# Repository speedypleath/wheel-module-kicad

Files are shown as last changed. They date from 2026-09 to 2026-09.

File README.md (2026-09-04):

# Haptic Console - Wheel Module (M3) Encoder Sensor Board

KiCad project for the electronics of the Wheel Module (M3) of Haptic Console v1.0,
part of the ITPMA dissertation *Tactile I/O: Exploring physicality in MIDI controllers*.

The mechanical side of this module (200 mm DIN aluminium handwheel, PETG shaft,
6204-2RS bearings, GT2 1:1 belt drive) is documented in the Obsidian vault under
`Notes/Haptic Console - Handwheel Belt Drive Module Plan.md`. This repository covers
only the sensor board that reads the optical encoder and presents it to the console.

## What the board does

The handwheel drives an E38S6G5-600B-G24N 600 P/R optical encoder through a 1:1 GT2
belt. A Raspberry Pi Pico reads the A/B quadrature signals locally, converts them into a clean position
packet, and exposes that packet to the Teensy 4.1 master over I2C. The module behaves
as a self-contained tactile sense organ rather than a peer processor, matching the
connector standard's design philosophy.

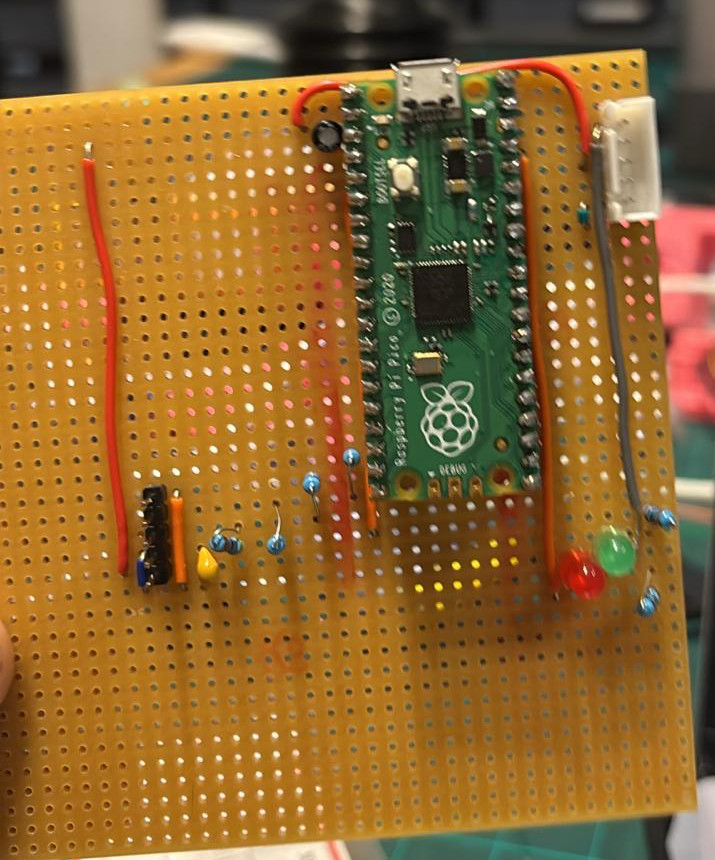
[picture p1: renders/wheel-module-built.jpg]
The Wheel Module encoder board, hand-wired on 2.54 mm protoboard


*The module as actually built. Component side, left to right: `J2` (black 5-pin encoder
header) and the pull-up/series resistors bottom left, `C2` (yellow disc) beside them,
`U1` centre with `C1`'s electrolytic can at its USB end, `J1` (white XH2.54 to the hub)
top right, and the `D1`/`D2` status LEDs bottom right.*

## The encoder interface, and why the pull-ups are there

The encoder is an **E38S6G5-600B-G24N**: photoelectric incremental, 600 P/R, rated
**DC 5-24V**, with **NPN open-collector** outputs. The `600B` suffix denotes **AB
two-phase — there is no Z index channel**. Absolute zero is established in firmware,
not from hardware index.

The open-collector output is the important electrical detail. An open-collector output can
only pull its line *low*. It never drives a line high. The high level is therefore set
entirely by whatever rail the line is pulled up to, and is completely independent of
the encoder's own supply voltage.

That gives the safety property this board relies on:

- `R1`, `R2` (4.7k) pull `ENC_A_RAW` and `ENC_B_RAW` up to **+3V3**.
- The Pico therefore sees a 0V to 3.3V swing regardless of whether the encoder is run
  from 5V or 12V.
- `R4`, `R5` (330R) sit in series into the Pico GPIO as fault-current limiters,
  protecting the pin if a line is ever accidentally shorted to the encoder supply.

4.7k is comfortable here. With ~2 m of encoder cable at roughly 120 pF/m plus pin and
stray capacitance (~300 pF total), the RC rise time is about 3 us 10-90%. At a realistic
handwheel speed of 300 rev/min each channel runs at 3 kHz, a 333 us period, so the rise
occupies under 1% of it. Pull-up current is 0.7 mA per line, far inside the output
stage's sink capability.

Without the pull-ups the inputs would float and the quadrature decode would be noise.
The pull-ups are not optional here.

Encoder power is taken from the console's **5V rail**, which is inside the encoder's
rated 5-24V window. If the encoder proves sluggish or noisy at 5V, the documented
alternative is a small 5V to 12V boost feeding `J2` pin 1 only. Because the pull-ups
reference 3.3V, that change requires **no** modification to the logic side.

**Decision, 2026-08-28: the 12V path is deliberately not built.** The planned Eurorack
translation module needs 24V regardless, so if a higher-voltage rail is ever added it
should be designed once for both modules rather than bolted onto M3 alone. Treat 5V as
the committed supply until that point. Note also that if the encoder signals ever look
sluggish, supply voltage is the *less* likely cause: edge shape here is set by the
pull-up RC (4.7k against ~300 pF, ~3 us) which does not change with encoder supply at
all. Rounded edges point at the pull-ups (fit 2.2k or 1k); missed counts that worsen
with rotation speed point at the supply.

## Console interface

`J1` is the standard **XH2.54 6-pin** inter-module connector (standard v1.1):

| Pin | Signal | Board use |
|---|---|---|
| 1 | GND | Common ground |
| 2 | 3.3V | **Not connected** (see below) |
| 3 | 5V | Powers the Pico via VSYS, and the encoder |
| 4 | SIG1 / SDA | I2C data, Pico GP4 |
| 5 | SIG2 / SCL | I2C clock, Pico GP5 |
| 6 | SIG3 / IRQ | Data-ready, Pico GP6 |

Pin 2 is deliberately left unconnected. The connector standard warns against feeding
both VSYS and 3V3 as competing power paths into a Pico. The board takes 5V into VSYS
and uses the Pico's own regulated 3V3 output as the logic reference for the pull-ups.

I2C bus pull-ups live on the master/hub board, not here, per the same standard.

## Encoder connector

`J2` is a 5-pin 2.54mm header matching the encoder's four conductors plus its shield:

| Pin | Encoder wire | Board use |
|---|---|---|
| 1 | Red | V+, from the console 5V rail |
| 2 | Black | 0V / GND |
| 3 | White | Channel A, to `R1`/`R4` |
| 4 | Green | Channel B, to `R2`/`R5` |
| 5 | Bare / foil | Cable shield, to GND |

Pin 5 carried `ENC_Z` in the first revision. The encoder has no Z channel, so it is now
the shield return, terminated to GND **at the board end only** — single-point, to avoid
a ground loop down the 2 m cable run.

## Pin map

| Pico pin | Net | Function |
|---|---|---|
| GP2 (pin 4) | LNK | Link/comms status LED |
| GP4 (pin 6) | SDA | I2C target data |
| GP5 (pin 7) | SCL | I2C target clock |
| GP6 (pin 9) | IRQ | Data-ready out to master |
| GP16 (pin 21) | ENC_A | Encoder channel A |
| GP17 (pin 22) | ENC_B | Encoder channel B |
| VSYS (pin 39) | +5V | Module power in |
| 3V3 (pin 36) | +3V3 | Logic reference out |

At 600 P/R with 4x quadrature decoding, one full handwheel turn is 2400 counts.

## Why C1 is there, and why it is an electrolytic

C1 is a **bulk reservoir**, not a decoupling capacitor, and the two jobs are
different. C2 (100 nF on 3V3) is decoupling: it kills the nanosecond-scale current
spikes from GPIO switching, and wants to be small and close to the pin. C1 sits on
the 5 V rail at the connector entry and does the opposite job — it is a local charge
store at the far end of the hub cable.

The 5 V arrives over a metre or two of XH2.54 flying lead, perhaps 1 uH/m of
inductance plus some milliohms. Every change in this board's load current has to be
supplied through that inductance: the encoder's output transistors switching at
2 x 3 kHz, the Pico's RT6150 buck-boost drawing pulsed input current, and above all
**hot-plugging J2 with the encoder attached**. Without local bulk the rail at VSYS
dips and rings instead of holding up. Steady-state draw is modest — encoder
40-100 mA, Pico 25-30 mA, LEDs ~3 mA — so it is the transients that matter.

100 nF will not do this job: it is 100x less charge. A 100 mA step lasting 300 ns
gives dV = I*dt/C ~= 300 mV on 100 nF against ~3 mV on 10 uF, and it moves the
cable-inductance resonance from ~50 kHz up to ~500 kHz where it is far less damped.

**Electrolytic is the right part, not a compromise** — bulk capacitance is what
aluminium electrolytics are for. The first revision specified a 10 uF ceramic only
because `Device:CP` cached as a zero-pin stub during project creation and switching
to the non-polarised `Device:C` sidestepped the question. (The real cause was
simpler: KiCad 10 has no `Device:CP` at all; the symbol is `Device:C_Polarized`.)

**C1 is now polarised, and nothing in ERC or DRC will catch it if you fit it
backwards.** Pad 1 is **+** and goes to `+5V`; the lead beside the printed stripe is
**-** and goes to `GND`. On a 5 V rail a reversed electrolytic will vent. Both build
guides call this out at the step where it matters.

## Bill of materials

| Ref | Value | Footprint |
|---|---|---|
| U1 | Raspberry Pi Pico | Module:RaspberryPi_Pico_Common_THT |
| J1 | XH2.54 6-pin console connector | Connector_JST:JST_XH_B6B-XH-A_1x06_P2.50mm_Vertical |
| J2 | 5-pin encoder header | Connector_PinHeader_2.54mm:PinHeader_1x05_P2.54mm_Vertical |
| R1, R2 | 4.7k pull-up to 3.3V | Resistor_THT:R_Axial_DIN0207_L6.3mm_D2.5mm_P10.16mm_Horizontal |
| R4, R5 | 330R series protection | Resistor_THT:R_Axial_DIN0207_L6.3mm_D2.5mm_P10.16mm_Horizontal |
| R7, R8 | 1k LED current limit | Resistor_THT:R_Axial_DIN0207_L6.3mm_D2.5mm_P10.16mm_Horizontal |
| C1 | 10uF 25V bulk on 5V, **polarised** | wheel-module:CP_Radial_D4.0mm_P2.50mm |
| C2 | 100nF decoupling on 3.3V | Capacitor_THT:C_Disc_D5.0mm_W2.5mm_P5.00mm |
| D1 | PWR green 3mm | LED_THT:LED_D3.0mm |
| D2 | LNK red 3mm | LED_THT:LED_D3.0mm |

D1 and D2 match the PWR/LNK status cluster in the front panel drawing
(`Notes/Haptic Console - Wheel Module Front Panel.md`).

## Layouts and build guides

One schematic, three board files. They share the netlist and nothing else — pick the one
that matches how you are building.

| Build | Board file | Build guide |
|---|---|---|
| Stripboard (Veroboard) | `project/haptic-console-wheel-module-stripboard.kicad_pcb` | [`docs/stripboard-wiring.md`](docs/stripboard-wiring.md), or the interactive [`docs/stripboard-wiring.html`](docs/stripboard-wiring.html) with a live board map |
| Plain perfboard | `project/haptic-console-wheel-module-perfboard.kicad_pcb` | [`docs/perfboard-wiring.md`](docs/perfboard-wiring.md) |
| Fabricated PCB | `project/haptic-console-wheel-module.kicad_pcb` | none needed — [Gerber set](project/haptic-console-wheel-module-gerbers.zip) |

### Schematic

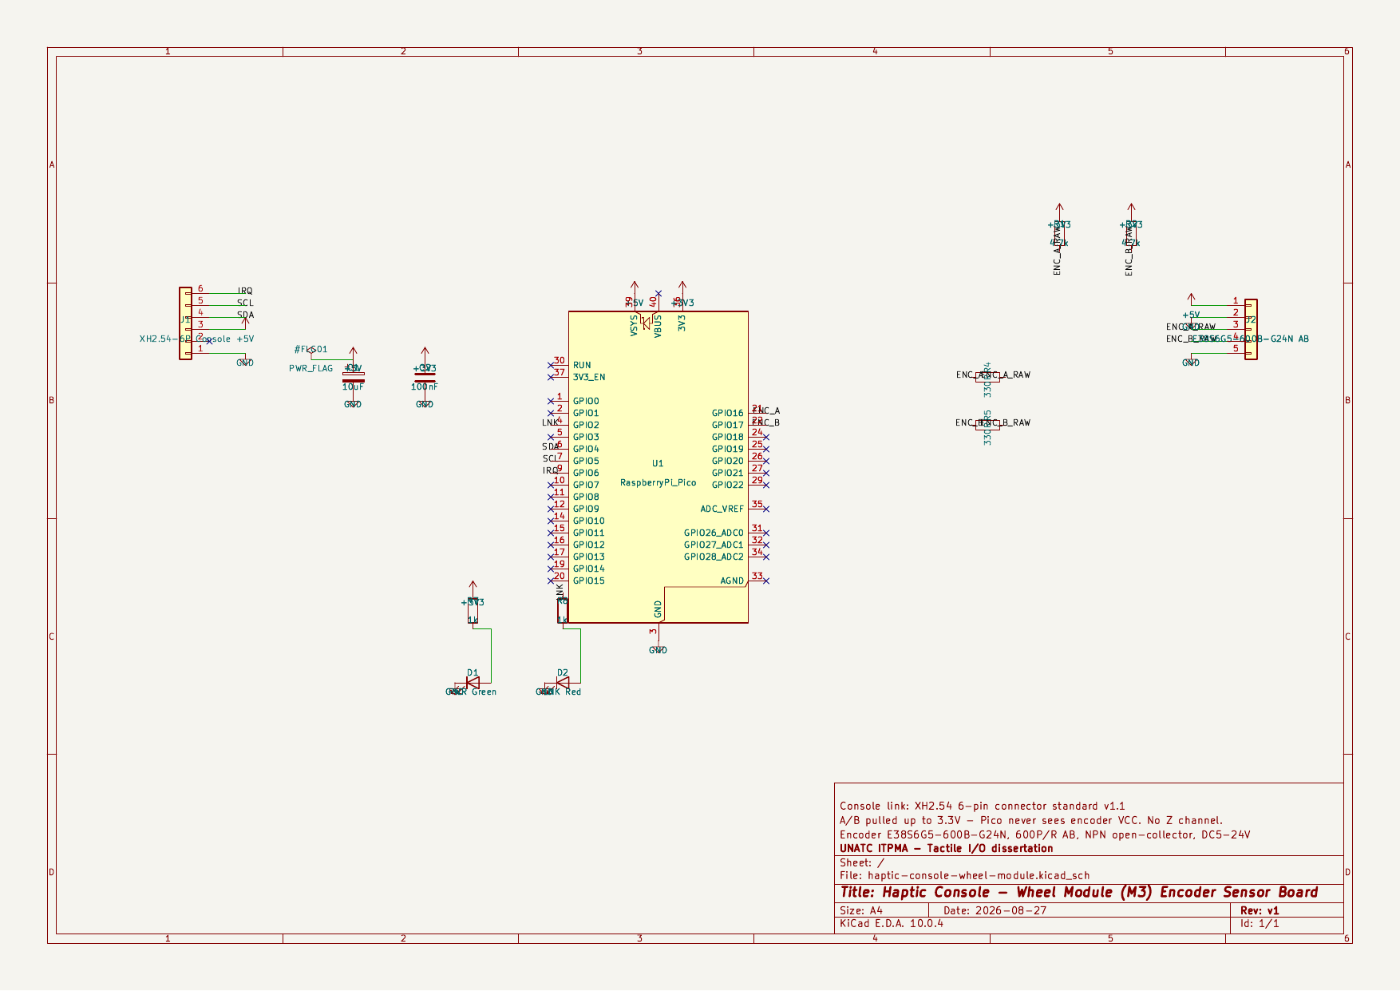
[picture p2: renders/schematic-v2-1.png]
Schematic


Full page as [`renders/schematic-v2.pdf`](renders/schematic-v2.pdf). ERC report:
[`docs/erc-report.txt`](docs/erc-report.txt); exported netlist:
[`docs/netlist.net`](docs/netlist.net).

### Stripboard (Veroboard)

40 x 40 holes, 104.14 mm square — the full uncut board. The circuit lives in cols 1-28 /
rows 1-28; the strips run the board's whole width regardless, which is why the audit
matters more than the placement.

| Component side | Solder side |
|---|---|
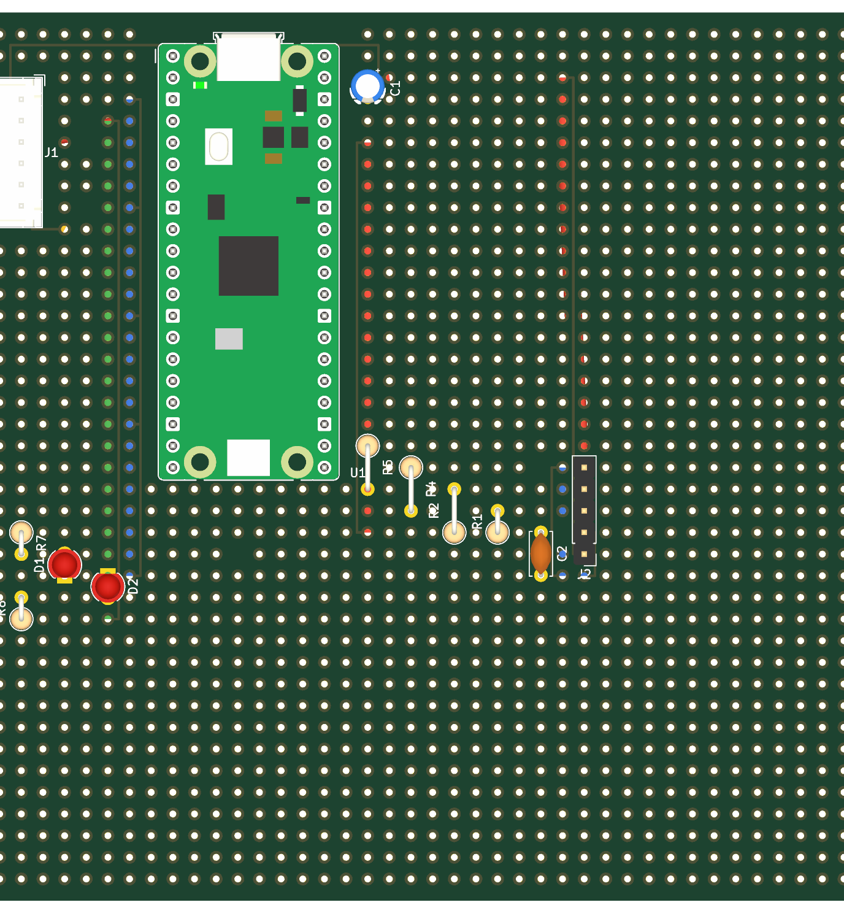
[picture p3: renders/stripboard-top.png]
Stripboard, component side
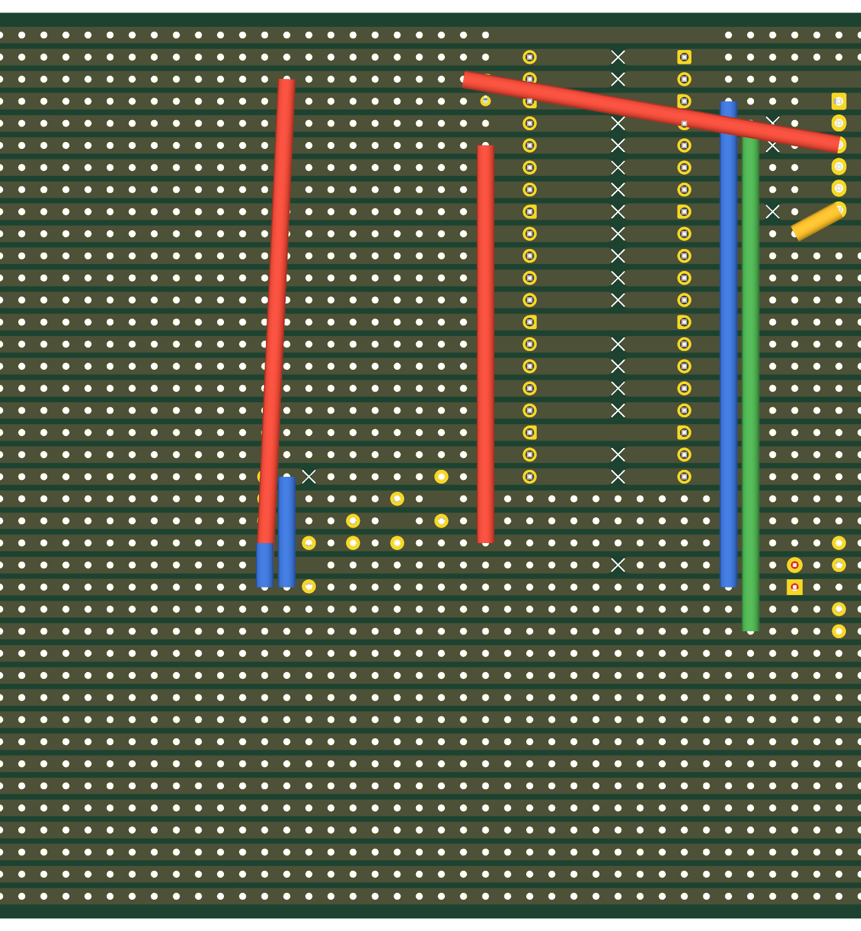
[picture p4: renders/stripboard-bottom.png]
Stripboard, solder side
|  |  |

The solder-side view is the one to build from: white `X` marks are the 23 track cuts, and
the coloured rods are the eight link wires, drawn to the control unit's colour convention
(red power, blue GND, yellow I2C/IRQ, green `/LNK`). Cuts and links are listed
step-by-step in [`docs/stripboard-wiring.md`](docs/stripboard-wiring.md).

### Plain perfboard

28 x 28 holes, 71.12 mm square, every connection a discrete wire.

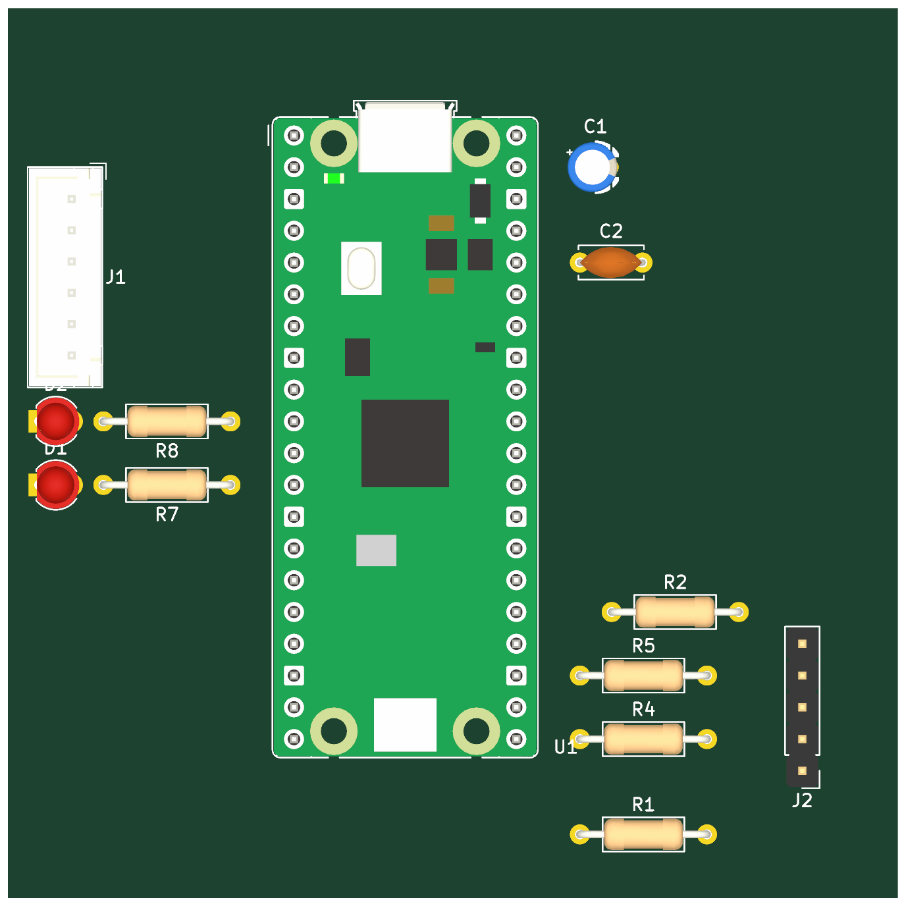
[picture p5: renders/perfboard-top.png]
Perfboard, component side


Wire-by-wire build order in [`docs/perfboard-wiring.md`](docs/perfboard-wiring.md).

### Fabricated PCB

68 x 58 mm, 2-layer, all through-hole.

| Front (F.Cu) | Back (B.Cu) |
|---|---|
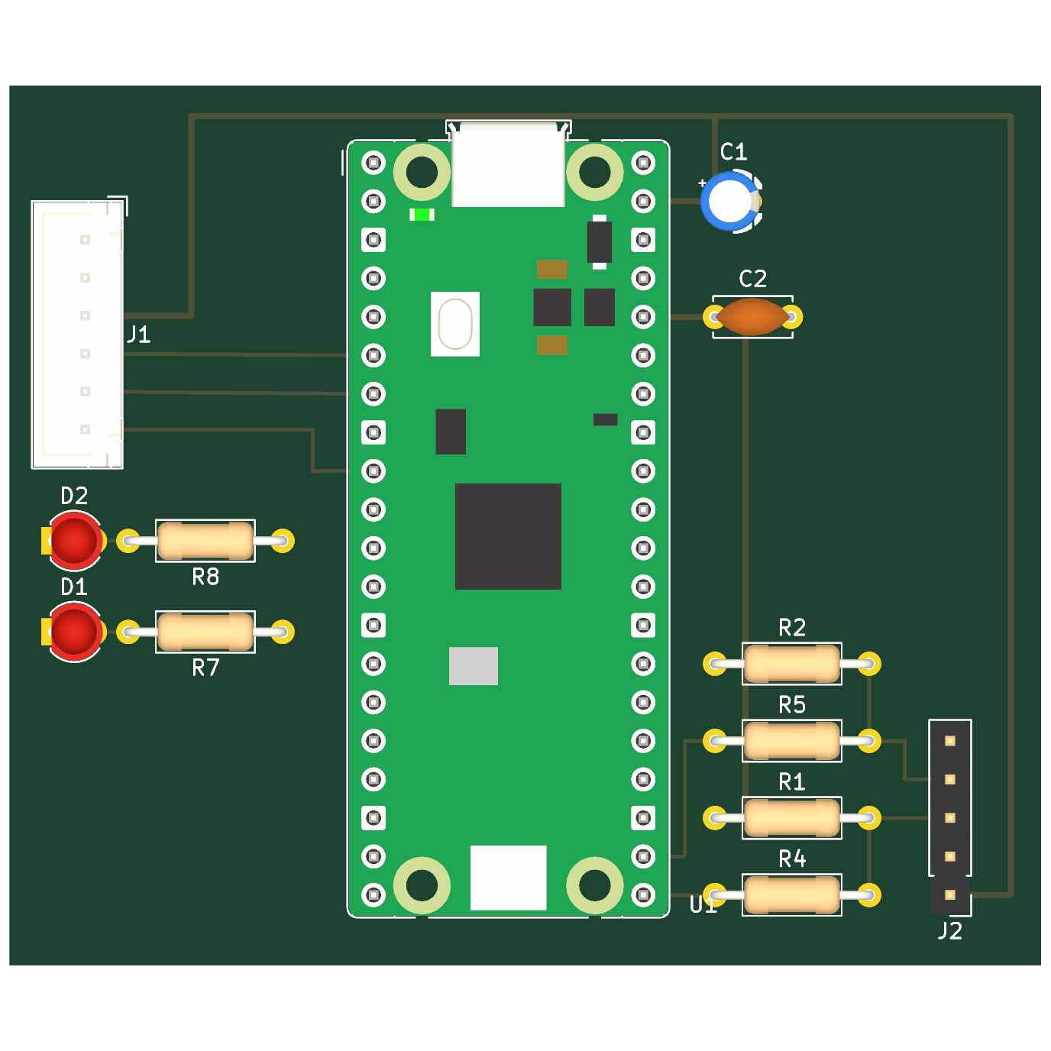
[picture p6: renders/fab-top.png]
Fabricated PCB, front
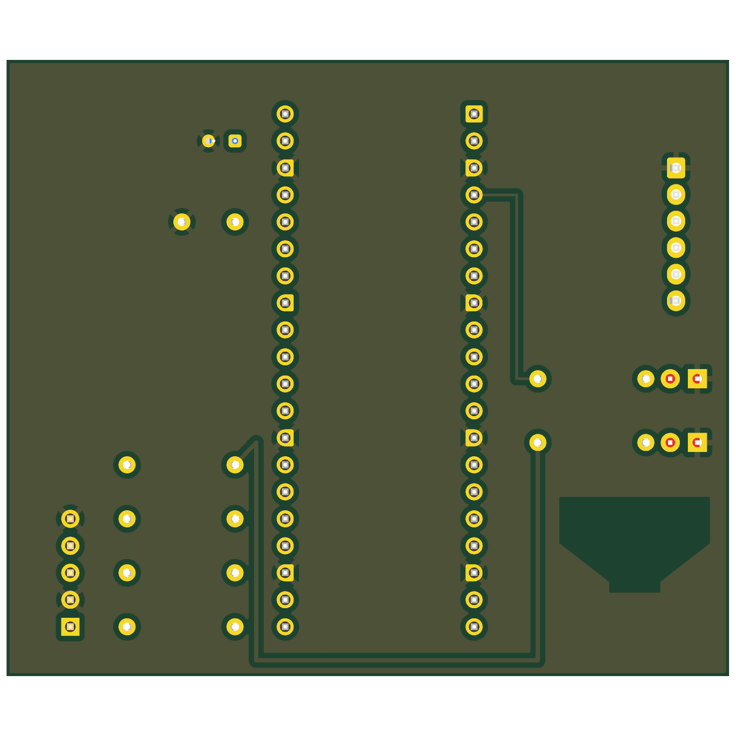
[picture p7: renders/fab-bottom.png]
Fabricated PCB, back
|  |  |

The back is mostly the filled GND pour that all 14 GND pads tie into; only `/LNK` and the
`+3V3` branch to `R7` are routed there.

## Status

- Schematic: complete, **ERC 0 errors / 0 warnings**, netlist verified by parsing the
  exported `docs/netlist.net` — 13 components, 15 nets, every node checked against the
  pin map above. A clean ERC alone does not prove connectivity; always read the netlist.
- Encoder revision: `ENC_Z`, `R3` and `R6` removed after the datasheet confirmed the
  `600B` part is AB two-phase. `J2` pin 5 repurposed as shield. GP18 is now free.
- Perfboard layout: **complete**, 28x28 holes on 2.54mm pitch (71.12 x 71.12 mm cut),
  **0 DRC errors / 9 cosmetic warnings**. Every pad verified on-grid with no shared
  holes. The 32 unconnected pads DRC reports are expected -
  the board is hand-wired and carries no copper traces.
- Stripboard (Veroboard) layout: **complete**, 40x40 holes on 2.54mm pitch
  (104.14 mm square, the full uncut board), **0 DRC errors / 0 unconnected pads**.
  The circuit occupies cols 1-28 / rows 1-28; the rest is spare board, but the
  strips still run its full width. Continuous copper
  strips, 23 track cuts, 11 link connections. Two cuts are
  load-bearing: row 9 keeps **AGND** off the GND bus, and column 5 keeps `J1` pin 2
  (hub 3.3V) unconnected. Rows 4/14/19 are left uncut on purpose - they carry GND on
  both sides of the Pico and form the GND bus for free. The ~240 DRC warnings are
  expected: perfboard holes modelled as vias dangle by construction.
  Generated from `scripts/layout.py` by the shared `~/KiCad/kicad-stripboard`
  engine - rebuild it rather than editing the board.
  The eight physical link wires are modelled as colour-coded 3D jumper wires on the
  **solder** side, keeping the crowded component side clear.
- Manufactured PCB layout: **complete**, 2-layer, 68 x 58 mm, all through-hole.
  **0 DRC errors, 0 shorts, 0 unconnected items** — every net is connected. 38 routed
  segments plus a filled GND pour on `B.Cu` (3270 mm² of copper), which all 14 GND pads
  tie into directly, so GND needs no traces. Two runs sit on the back layer because they would otherwise cross the J1 signal fan
  on the front: `/LNK` (U1.4 → R8.1) and the `+3V3` branch feeding R7, which goes round
  the bottom at y=56.5 rather than threading the 0.94 mm gaps between the Pico's pad
  rows. The front `+3V3` spine is offset to x=48.5 rather than running down the x=46.5
  pad column, because R5.1 (`/ENC_B`) sits mid-column at 46.5,43.18.
- Cosmetic: reference and value text is auto-placed and overlaps net labels in a few
  places. Harmless electrically, but worth a tidy-up pass in the GUI before the
  schematic goes into the dissertation.

## Verification

```bash
export KICAD_SYMBOL_DIR=/Applications/KiCad/KiCad.app/Contents/SharedSupport/symbols
export KICAD_FOOTPRINT_DIR=/Applications/KiCad/KiCad.app/Contents/SharedSupport/footprints
kicad-cli sch erc --format report project/haptic-console-wheel-module.kicad_sch -o docs/erc-report.txt
kicad-cli sch export netlist --format kicadsexpr project/haptic-console-wheel-module.kicad_sch -o docs/netlist.net
```

Setting both environment variables matters. Without them `kicad-cli` cannot resolve the
stock libraries and reports spurious violations.

## Related

- [`docs/perfboard-wiring.md`](docs/perfboard-wiring.md) - hand-wiring guide for the
  plain-perfboard build
- [`docs/stripboard-wiring.md`](docs/stripboard-wiring.md) - cut/link build guide for the
  Veroboard build, plus the interactive
  [`docs/stripboard-wiring.html`](docs/stripboard-wiring.html)
- [`scripts/layout.py`](scripts/layout.py) - the stripboard layout as data; source of
  truth for that board
- `../kicad-stripboard` - the shared engine that builds and audits strip board layouts
- `../control-unit-kicad` - the Control Unit (M6) board, already fab-ready
- Obsidian: `Notes/Haptic Console - Connector Standard.md`
- Obsidian: `concepts/haptic-console-wheel-module.md`

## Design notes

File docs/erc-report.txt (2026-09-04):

ERC report (2026-09-03T21:16:04, Encoding UTF8)
Report includes: Errors, Warnings

***** Sheet /

 ** ERC messages: 0  Errors 0  Warnings 0

 ** Ignored checks:
    - Global label only appears once in the schematic
    - Four connection points are joined together
    - Assigned footprint doesn't match footprint filters

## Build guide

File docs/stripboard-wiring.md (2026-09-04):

# Stripboard wiring guide — Wheel Module (M3) encoder sensor board

Build reference for `project/haptic-console-wheel-module-stripboard.kicad_pcb`.
Generated from the placed board; grid resized to the real 40 x 40 stock on
2026-08-30. Circuit itself is in `README.md`.

There is an interactive version of this document at
[`docs/stripboard-wiring.html`](stripboard-wiring.html) — same content, plus a
board map, a searchable cut list and a tickable solder checklist. Open it in a
browser; it is a single self-contained file.

This is the **Veroboard** build. It is a different board from
`docs/perfboard-wiring.md`, which covers the point-to-point plain-perfboard build.
Pick one; they are not interchangeable.

## Grid convention

Continuous-strip Veroboard, **40 columns × 40 rows** on 2.54 mm — a full
**104.14 mm square** board, uncut. Copper strips run **horizontally**, one per
row, the full width of the board.

```
x = col * 2.54 mm        col 1..40, left to right
y = row * 2.54 mm        row 1..40, top to bottom
```

The circuit occupies **cols 1–28, rows 1–28**, in the top-left corner. Everything
right of column 28 and below row 28 is spare board. That spare copper is not
inert: each strip still runs the full 40 columns, so the right-hand end of a row
is electrically the same node as the part of it the circuit uses. Treat it as
free tie points, and keep it clear of stray solder bridges between rows.

`(1,1)` is the top-left hole, with one clear 2.54 mm margin on every edge. All
column/row references below are given **component side, Pico USB at the top** —
matching `renders/stripboard-top.png`. Remember the copper is on the **back**, so
when you flip the board to cut, columns mirror.

**Row 1 carries nothing.** The Pico's body is 51 mm long but spans only 19 pin
pitches (48.26 mm), so it overhangs its end rows by 1.37 mm: the body edge sits
at y = 3.71 mm while a row-1 hole's copper ends at 3.29 mm. That is 0.42 mm of
daylight — real, but not worth soldering into. The USB shell overhangs a further
1.3 mm on top of that, though it rides 8.5 mm up in the air on the socket
headers and fouls nothing.

## Read this first: the strip is shared by every hole in its row

On plain perfboard a hole connects to nothing. Here it connects to the whole row.
So a pin you never wired still shorts to whatever else sits on its strip. Two
consequences drove this entire layout:

- **Row 9 must be cut at column 12.** Pico pin 8 (GND) is on the left of that
  row and pin 33 (**AGND**) is on the right. AGND is a deliberate no-connect —
  tying it to GND re-creates the `power_out`/`power_out` ERC violation documented
  in `CLAUDE.md`. Leave that cut out and you have broken a design invariant.
- **Rows 4, 14 and 19 are deliberately NOT cut.** Those three rows carry GND on
  *both* sides of the Pico (pins 3/38, 13/28, 18/23), so leaving them whole gives
  six GND connections for free and forms the GND bus.

### And why `+5V` has no strip of its own

A strip that spans the Pico is only safe on a row whose two pins are the same
net, and the only such rows are the three GND ones. So `+5V` cannot have a
full-width rail. It lives on **row 3's right-hand segment**, where the Pico's
own VSYS pin and `C1` already sit, and the hub's 5 V — which arrives on the far
left at `J1.3` — is carried over the top of the module to reach it (wire 1).
Row 3's *left* segment must stay cut off at column 12: it carries Pico pin 2,
GPIO1, and 5 V on a GPIO would destroy the chip.

## Cuts — 23 of them

Cut with a spot-face cutter or a 3 mm drill twisted by hand, **at the hole**,
from the copper side. Each cut removes the copper around one hole; that hole is
then dead. Marked with an `X` on the back silkscreen in the render.

| Column | Rows | Why |
|---|---|---|
| **12** | 2, 3, 5, 6, 7, 8, 9, 10, 11, 12, 13, 15, 16, 17, 18, 20, 21 | Splits the Pico's left pins from its right pins. **Not** 4/14/19 — those stay whole as the GND bus. |
| **12** | 25 | Separates `Net-(D1-A)` (left) from `+5V` (right). |
| **5** | 5, 6, 9 | Isolates `J1` pins 2, 3 and 6, whose order disagrees with the Pico's. |
| **26** | 21 | Isolates `J2.5` (shield GND) from `/ENC_A`. |
| **27** | 24 | Isolates `J2.2` (GND) from `+3V3`. |

Count them before soldering anything. A missed cut on row 9 or row 3 is the
expensive kind.

## Strip allocation

Every strip segment carries exactly one net — verified against the saved board,
not against intent.

| Row | Columns | Net | Pads on it |
|---|---|---|---|
| 1 | all | *(spare — under the module overhang)* | — |
| 2 | 1–11 / 13–40 | *(unused Pico pins)* | U1.1 / U1.40 |
| 3 | 1–11 | *(unused)* | U1.2 |
| 3 | 13–40 | `+5V` | U1.39, C1.1 |
| **4** | **all (uncut)** | `GND` | U1.3, U1.38, J1.1, C1.2 |
| 5 | 1–4 | *(no-connect)* | **J1.2 — hub 3.3V, must stay isolated** |
| 5 | 6–11 | `/LNK` | U1.4 |
| 5 | 13–40 | *(unused)* | U1.37 |
| 6 | 1–4 | `+5V` | J1.3 |
| 6 | 6–11 | *(unused)* | U1.5 |
| 6 | 13–40 | `+3V3` | U1.36 |
| 7 | 1–11 | `/SDA` | U1.6, J1.4 |
| 7 | 13–40 | *(unused)* | U1.35 |
| 8 | 1–11 | `/SCL` | U1.7, J1.5 |
| 8 | 13–40 | *(unused)* | U1.34 |
| 9 | 1–4 | `/IRQ` | J1.6 |
| 9 | 6–11 | `GND` | U1.8 |
| 9 | 13–40 | *(no-connect)* | **U1.33 AGND — must stay isolated** |
| 10 | 1–11 | `/IRQ` | U1.9 |
| 10 | 13–40 | *(unused)* | U1.32 |
| 11–13, 15–18 | 1–11 / 13–40 | *(unused Pico pins)* | one per side, bare |
| **14** | **all (uncut)** | `GND` | U1.13, U1.28 |
| **19** | **all (uncut)** | `GND` | U1.18, U1.23 |
| 20 | 1–11 | *(unused)* | U1.19 |
| 20 | 13–40 | `/ENC_B` | U1.22, R5.1 |
| 21 | 1–11 | *(unused)* | U1.20 |
| 21 | 13–25 | `/ENC_A` | U1.21, R4.1 |
| 21 | 27–40 | `GND` | J2.5 |
| 22 | all | `/ENC_B_RAW` | R5.2, R2.2, J2.4 |
| 23 | all | `/ENC_A_RAW` | R4.2, R1.2, J2.3 |
| 24 | 1–26 | `+3V3` | R7.1, R2.1, R1.1, C2.1 |
| 24 | 28–40 | `GND` | J2.2 |
| 25 | 1–11 | `Net-(D1-A)` | R7.2, D1.2 |
| 25 | 13–40 | `+5V` | J2.1 |
| 26 | all | `GND` | D1.1, D2.1, C2.2 |
| 27 | all | `Net-(D2-A)` | D2.2, R8.2 |
| 28 | all | `/LNK` | R8.1 |
| 29–40 | all | *(spare board)* | — |

63 strip segments in total, across 1331 holes.

## Placement

Pad 1 sits at the stated hole for every part. **All six resistors stand on end**
— this is the Veroboard idiom and it is what stops them shorting along a strip.

| Ref | Value | Footprint | Pad 1 | Occupies |
|---|---|---|---|---|
| U1 | Pico | `RaspberryPi_Pico_Common_THT` | (9,2) | cols 9 & 16, rows 2–21 |
| J1 | XH2.54 6-pin | `JST_XH_B6B-XH-A_1x06_P2.50mm_Vertical` | (2,4) | col 2, rows 4–9 |
| J2 | 5-pin header | `PinHeader_1x05_P2.54mm_Vertical` | (28,25) | col 28, rows 21–25, **pin 1 at the bottom** |
| R1 | 4.7k | `R_Axial_..._P2.54mm_Vertical` | (24,24) | col 24, rows 23–24 |
| R2 | 4.7k | `R_Axial_..._P5.08mm_Vertical` | (22,24) | col 22, rows 22–24 |
| R4 | 330R | `R_Axial_..._P5.08mm_Vertical` | (20,21) | col 20, rows 21–23 |
| R5 | 330R | `R_Axial_..._P5.08mm_Vertical` | (18,20) | col 18, rows 20–22 |
| R7 | 1k | `R_Axial_..._P2.54mm_Vertical` | (2,24) | col 2, rows 24–25 |
| R8 | 1k | `R_Axial_..._P2.54mm_Vertical` | (2,28) | col 2, rows 27–28 |
| C1 | 10uF 25V | `wheel-module:CP_Radial_D4.0mm_P2.50mm` | (18,3) | col 18, rows 3–4, **pad 1 = + = row 3** |
| C2 | 100nF | `C_Disc_D5.0mm_W2.5mm_P5.00mm` | (26,24) | col 26, rows 24–26 |
| D1 | power LED | `LED_D3.0mm` | (4,26) | col 4, rows 25–26, pad 1 = cathode = GND |
| D2 | link LED | `LED_D3.0mm` | (6,26) | col 6, rows 26–27, pad 1 = cathode = GND |

**C1 is polarised.** It is a D4x7 aluminium electrolytic, not the ceramic disc the
first revision carried. Pad 1 is the **+** lead and belongs on row 3 (the `+5V` strip);
the lead beside the printed stripe is **−** and goes to row 4 (`GND`). Fitted the wrong
way round it can vent. Its footprint is drawn project-local, in
`libraries/wheel-module.pretty`: no stock `CP_Radial` pairs a 4 mm can with the
2.50 mm pitch the 2.54 mm grid needs, and the stock 5 mm can is 1 mm too wide —
wide enough that its courtyard overlapped the Pico here and pushed C1 three holes
right for no physical reason.

Two parts are very slightly off-grid and this is fine — the leads bend:

- `J1` is a 2.50 mm connector on a 2.54 mm grid: pin 6 lands 0.2 mm above row 9,
  cumulative over six pins. XH pins are 0.6 mm in 1.0 mm holes.
- `C1` (2.50 mm) and `C2` (5.00 mm) are 0.04 mm and 0.08 mm out respectively.

`R4` and `R5` are the nicest part of this layout: they reach straight from the
Pico's `/ENC_A`/`/ENC_B` pins down to the `_RAW` rows with **no link wire at
all**, so the two noise-sensitive nets are pure copper.

## Link wires — 8 of them

**Insulated wire on the solder side**, hole to hole. The component side is
crowded — the Pico spans twenty rows and `J1`, `J2` and the LEDs sit on the very
edges the long links follow — so wires there would lie across component bodies.
The back is flat: insulated wire over a copper strip touches nothing.

Colours follow the console convention, shared with the control unit so the same
net is the same colour on every board: **red** for power (`+5V` and `+3V3` both —
the kit has six colours and consistency across boards wins over telling the two
rails apart at a glance), **blue** for GND (the kit has no black), **yellow** for
the I²C/IRQ bus, **green** for `/LNK`.

| # | Net | Colour | From | To | Purpose |
|---|---|---|---|---|---|
| 1 | `+5V` | red | (2,6) `J1.3` | (19,3) | console 5V over the module to the `+5V` rail |
| 2 | `/IRQ` | yellow | (2,9) `J1.6` | (4,10) | J1's IRQ pin down to the Pico's |
| 3 | `+5V` | red | (27,3) | (28,25) `J2.1` | rail down to the encoder connector |
| 4 | `+3V3` | red | (18,6) | (18,24) | Pico 3V3 out to the pull-up rail |
| 5 | `/LNK` | green | (6,5) | (6,28) | Pico GP2 down to the LED resistor |
| 6 | `GND` | blue | (7,4) | (7,26) | GND spine — **solder it also at rows 9, 14 and 19 on the way past** |
| 7 | `GND` | blue | (27,21) | (27,26) | `J2.5` cable shield to GND |
| 8 | `GND` | blue | (28,24) | (28,26) | `J2.2` encoder GND to GND |

Wire 6 is one length soldered at five holes — rows 4, 9, 14, 19 and 26. Those
three intermediate joints are what tie the Pico's GND rows into one bus; skipping
any of them leaves that row floating. (The board file models them as three extra
zero-length links, which is why the netlist counts eleven and this table eight.)

Wire 1 is the long one. It runs from `J1.3` up the outside of column 2, across
above the module in the gutter between rows 1 and 2, and down to (19,3). Its
copper track passes 1.27 mm from the row-2 Pico pins — 0.32 mm of clearance — so
keep the physical wire pulled up against the module's top edge rather than
letting it wander down over the pins. It crosses wires 5 and 6 on the way; all
three are insulated, so let 1 lie over them.

Wire 8 passes directly over `J2` pin 1, where wire 3 lands. Both are insulated —
let 8 lie over 3 rather than trying to dodge it.

## Optical Encoder (J2) & Console (J1) External Wiring

### Optical Encoder Wiring (`J2` — 5-Pin Header)

Target Encoder: **E38S6G5-600B-G24N** (NPN open-collector, 600 P/R).

| `J2` Pin | Stripboard Position (Col, Row) | Board Net | Encoder Wire Color | Function / Signal Path |
|---|---|---|---|---|
| **Pin 1** | **(28, 25)** *(Bottom)* | `+5V` | **Red** | Encoder DC Power Supply (+5V) |
| **Pin 2** | **(28, 24)** | `GND` | **Black** | Encoder Power Ground (0V) |
| **Pin 3** | **(28, 23)** | `/ENC_A_RAW` | **White** | Phase A &rarr; pull-up `R1` (4.7k) &rarr; `R4` (330R) &rarr; Pico `GP16` |
| **Pin 4** | **(28, 22)** | `/ENC_B_RAW` | **Green** | Phase B &rarr; pull-up `R2` (4.7k) &rarr; `R5` (330R) &rarr; Pico `GP17` |
| **Pin 5** | **(28, 21)** *(Top)* | `GND` (Shield) | **Bare / Braid** | Cable shield drain (single-point to board GND) |

#### Physical Header Orientation (Component Side, Pico USB UP):
```text
               [ Pico USB Top ]
  
  (Col 28, Row 21)  [ Pin 5 ]  <--- BARE BRAID (Cable Shield)
  (Col 28, Row 22)  [ Pin 4 ]  <--- GREEN      (Phase B)
  (Col 28, Row 23)  [ Pin 3 ]  <--- WHITE      (Phase A)
  (Col 28, Row 24)  [ Pin 2 ]  <--- BLACK      (Ground 0V)
  (Col 28, Row 25)  [ Pin 1 ]  <--- RED        (+5V Power)
  
              [ Bottom Edge ]
```

- **Shield Ground:** Terminate shield braid to Pin 5 *at this board end only* to prevent ground loops along the 2 m cable.
- **Open-Collector Logic:** Encoder outputs pull to GND; board pull-ups (`R1`, `R2`) pull up to +3.3V, ensuring Pico GPIO safety.
- **Pre-Flight DMM Checks:** Power board, measure Pin 1 &rarr; Pin 2 (+5.0V) and Pins 3/4 &rarr; GND (+3.3V) before plugging encoder in.

### Console Harness Wiring (`J1` — XH2.54 6-Pin Connector)

| `J1` Pin | Position (Col, Row) | Net | Function |
|---|---|---|---|
| **Pin 1** | **(2, 4)** *(Top)* | `GND` | Common system ground (Row 4 GND bus) |
| **Pin 2** | **(2, 5)** | `NC (Isolated)` | Console 3.3V &mdash; **must stay isolated** |
| **Pin 3** | **(2, 6)** | `+5V` | Console 5V DC power in &rarr; Pico VSYS |
| **Pin 4** | **(2, 7)** | `/SDA` | I²C Data &rarr; Pico `GP4` |
| **Pin 5** | **(2, 8)** | `/SCL` | I²C Clock &rarr; Pico `GP5` |
| **Pin 6** | **(2, 9)** *(Bottom)* | `/IRQ` | Interrupt line &rarr; Pico `GP6` |

## Build order

1. **Make all 23 cuts first**, before any part goes in. Check each one for
   continuity across the gap — a partial cut is the hardest fault to find later.
2. **Fit the Pico on female headers**, not soldered down. Two GND strips and the
   whole cut column run underneath it.
3. **Resistors, LEDs, caps.** All resistors vertical. Watch LED polarity: pad 1
   is the cathode and goes to the GND row (26) for both.
4. **`J1` and `J2`.**
5. **Link wires last.** They go on the *solder* side, so they follow the parts
   rather than preceding them: each end lands in the named hole and is soldered
   to that strip alongside the component lead already there. Strip and tin both
   ends first — a wire soldered onto an already-crowded joint is the easiest one
   to lift by accident.
6. Before power-up, check with a meter: `+5V` to `GND` open, `+3V3` to `GND`
   open, and **`U1.33` (AGND) isolated from GND** — that last one is the specific
   thing this layout's row-9 cut exists to guarantee.

## Verification state

- `kicad-cli pcb drc`: **0 errors, 0 unconnected pads, 0 footprint errors.**
- Strip audit (`every segment carries exactly one net`): **clean**, including the
  two isolation invariants above.
- 240 DRC *warnings* remain, all `via_dangling`/`track_dangling` plus three
  pre-existing `lib_footprint_mismatch`. These are expected — see `CLAUDE.md`.

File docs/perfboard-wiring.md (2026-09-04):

# Perfboard wiring guide — Wheel Module (M3) encoder sensor board

Hand-wiring reference for `project/haptic-console-wheel-module-perfboard.kicad_pcb`.
Generated from the placed board on 2026-08-28. Circuit itself is in `README.md`.

## Grid convention

Plain 2.54 mm perfboard, cut to **71.12 × 71.12 mm** (28 × 28 holes).

A hole is addressed as **(col, row)**, both 1-based from the top-left corner:

```
x = col * 2.54 mm        col 1..28, left to right
y = row * 2.54 mm        row 1..28, top to bottom
```

So (1,1) is the top-left hole and there is one clear 2.54 mm margin on every edge.
This matches the orientation of `renders/perfboard-top.png` — view from the
**component side**, Pico USB connector at the top.

## Placement summary

| Ref | Occupies | Notes |
|---|---|---|
| U1 Pico | cols 9 and 16, rows 4–23 | pin 1 at (9,4); left pin row descends, right pin row ascends |
| J1 console XH6 | col 2, rows 6–11 | pin 1 (GND) at top |
| J2 encoder 1x05 | col 25, rows 20–24 | **pin 1 at the bottom** (row 24), footprint is rotated 180° |
| R1, R2 | rows 26 and 19 | 4.7k pull-ups to +3V3 |
| R4, R5 | rows 23 and 21 | 330R series protection |
| R7, R8 | rows 15 and 13, cols 3–7 | 1k LED limiters, rotated 180° |
| D1, D2 | cols 1–2, rows 15 and 13 | pad 1 = cathode = GND |
| C1, C2 | C1 cols 18–19 row 5, C2 cols 18–20 row 8 | bulk (polarised) and decoupling |

Resistors sit two rows apart so the axial bodies never touch.

**C1 is polarised** — a 10 µF 25 V D4x7 electrolytic. Pad 1 is **+** and goes to (18,5)
on `+5V`; the striped **−** lead goes to (19,5) on `GND`. It spans two holes rather
than three because the electrolytic's leads are 2.5 mm apart, not 5 mm.

## Nets

| Net | Pads (col,row) |
|---|---|
| `+3V3` | **U1.36** (16,8) — **C2.1** (18,8) — **R7.1** (7,15) — **R2.1** (19,19) — **R1.1** (18,26) |
| `+5V` | **U1.39** (16,5) — **C1.1** (18,5) — **J1.3** (2,8) — **J2.1** (25,24) |
| `/ENC_A` | **U1.21** (16,23) — **R4.1** (18,23) |
| `/ENC_A_RAW` | **J2.3** (25,22) — **R4.2** (22,23) — **R1.2** (22,26) |
| `/ENC_B` | **R5.1** (18,21) — **U1.22** (16,22) |
| `/ENC_B_RAW` | **R2.2** (23,19) — **R5.2** (22,21) — **J2.4** (25,21) |
| `/IRQ` | **J1.6** (2,11) — **U1.9** (9,12) |
| `/LNK` | **U1.4** (9,7) — **R8.1** (7,13) |
| `/SCL` | **J1.5** (2,10) — **U1.7** (9,10) |
| `/SDA` | **J1.4** (2,9) — **U1.6** (9,9) |
| `GND` | **C1.2** (19,5) — **J1.1** (2,6) — **U1.3** (9,6) — **U1.38** (16,6) — **C2.2** (20,8) — **U1.8** (9,11) — **D2.1** (1,13) — **D1.1** (1,15) — **U1.13** (9,16) — **U1.28** (16,16) — **J2.5** (25,20) — **U1.18** (9,21) — **U1.23** (16,21) — **J2.2** (25,23) |
| `Net-(D1-A)` | **D1.2** (2,15) — **R7.2** (3,15) |
| `Net-(D2-A)` | **D2.2** (2,13) — **R8.2** (3,13) |

## Wiring notes, in build order

Solder in this order — shortest and most constrained runs first, so nothing is
trapped underneath a part you cannot reach later.

**1. Sockets and connectors first.** Fit the Pico on female headers rather than
soldering it down. Two of the runs below pass under it and you will want the
option of lifting it off.

**2. The free same-row runs.** These need one straight wire each, no jogs:

- `/SDA` — J1.4 (2,9) to U1.6 (9,9)
- `/SCL` — J1.5 (2,10) to U1.7 (9,10)
- `/ENC_A` — U1.21 (16,23) to R4.1 (18,23)
- `+5V` local — U1.39 (16,5) to C1.1 (18,5)
- `+3V3` local — U1.36 (16,8) to C2.1 (18,8)

**3. The one-hole jogs.** `/IRQ` J1.6 (2,11) to U1.9 (9,12), and `/ENC_B`
U1.22 (16,22) to R5.1 (18,21). The connector and Pico pin orders run opposite
ways here; one row of diagonal absorbs it.

**4. Encoder signal pairs.** Keep these short — they are the only nodes on the
board where edge quality matters:

- `/ENC_A_RAW` — R4.2 (22,23) up column 22 to R1.2 (22,26), then across to J2.3 (25,22)
- `/ENC_B_RAW` — R5.2 (22,21) across row 21 to J2.4 (25,21), and diagonally to R2.2 (23,19)

Column 22 carries `/ENC_A_RAW` on rows 23–26 and `/ENC_B_RAW` only at row 21, so
the two never share a segment. Do not let them.

**5. Rails last.** GND has 14 nodes and +3V3 has 5. Bus them along a shared row
or column rather than home-running each one.

## Two long runs, called out deliberately

**`+3V3` to R7.1 (7,15) crosses the Pico.** Everything else on +3V3 lives on the
right-hand side (cols 16–19); the PWR LED's resistor is on the left. Either run
this wire underneath the Pico before seating it, or take it the long way round
via row 25. Decide before step 1 — under the Pico is tidier but only reachable
while the module is off its socket.

**`+5V` from J1.3 (2,8) to U1.39 (16,5)** crosses the full board width. This is
unavoidable: the Pico's VSYS is pin 39 on the right-hand side while the console
connector has to be on the left, next to I2C. The trade was deliberate — SDA,
SCL and IRQ are the signal-integrity-sensitive nets and they got the short runs,
while +5V is a power rail with C1 bulk decoupling sitting directly at the Pico
pin. Route it along the top edge (row 2–3) rather than through the middle.

## Gotchas

- **J1 is 2.5 mm pitch on a 2.54 mm grid.** Over six pins that accumulates
  0.2 mm. It seats fine — this was already confirmed on the control-unit
  perfboard — but ease it in rather than forcing it.
- **J2 is rotated 180°**, so encoder pin 1 (red, V+) is the *bottom* hole at
  (25,24) and the shield is the *top* hole at (25,20). Easy to wire backwards.
- **D1/D2 pad 1 is the cathode** and goes to GND. Check the flat before soldering.
- **Encoder runs from the console 5V rail.** The 12V option is deliberately not
  built — see `README.md`.

## Verification

```bash
export KICAD_SYMBOL_DIR=/Applications/KiCad/KiCad.app/Contents/SharedSupport/symbols
export KICAD_FOOTPRINT_DIR=/Applications/KiCad/KiCad.app/Contents/SharedSupport/footprints
kicad-cli pcb drc --format report project/haptic-console-wheel-module-perfboard.kicad_pcb -o docs/drc-perfboard.txt
kicad-cli pcb render --side top --width 1400 --height 1400 -o renders/perfboard-top.png project/haptic-console-wheel-module-perfboard.kicad_pcb
```

Current state: **0 DRC errors, 9 warnings.** The warnings are five
`lib_footprint_mismatch` (tool-placed footprint copies differing cosmetically
from the library), three `silk_overlap` on D2's reference text under J1's
outline, and one `silk_over_copper` on U1's reference. All cosmetic.

The 32 "unconnected pads" DRC reports are **expected and correct** — this board
has no copper traces by design. Connectivity lives in the wire list above.

## Full pad reference

| Ref | Pad | Col | Row | Net |
|---|---|---|---|---|
| C1 | 1 | 18 | 5 | `+5V` |
| C1 | 2 | 19 | 5 | `GND` |
| C2 | 1 | 18 | 8 | `+3V3` |
| C2 | 2 | 20 | 8 | `GND` |
| D1 | 1 | 1 | 15 | `GND` |
| D1 | 2 | 2 | 15 | `Net-(D1-A)` |
| D2 | 1 | 1 | 13 | `GND` |
| D2 | 2 | 2 | 13 | `Net-(D2-A)` |
| J1 | 1 | 2 | 6 | `GND` |
| J1 | 3 | 2 | 8 | `+5V` |
| J1 | 4 | 2 | 9 | `/SDA` |
| J1 | 5 | 2 | 10 | `/SCL` |
| J1 | 6 | 2 | 11 | `/IRQ` |
| J2 | 1 | 25 | 24 | `+5V` |
| J2 | 2 | 25 | 23 | `GND` |
| J2 | 3 | 25 | 22 | `/ENC_A_RAW` |
| J2 | 4 | 25 | 21 | `/ENC_B_RAW` |
| J2 | 5 | 25 | 20 | `GND` |
| R1 | 1 | 18 | 26 | `+3V3` |
| R1 | 2 | 22 | 26 | `/ENC_A_RAW` |
| R2 | 1 | 19 | 19 | `+3V3` |
| R2 | 2 | 23 | 19 | `/ENC_B_RAW` |
| R4 | 1 | 18 | 23 | `/ENC_A` |
| R4 | 2 | 22 | 23 | `/ENC_A_RAW` |
| R5 | 1 | 18 | 21 | `/ENC_B` |
| R5 | 2 | 22 | 21 | `/ENC_B_RAW` |
| R7 | 1 | 7 | 15 | `+3V3` |
| R7 | 2 | 3 | 15 | `Net-(D1-A)` |
| R8 | 1 | 7 | 13 | `/LNK` |
| R8 | 2 | 3 | 13 | `Net-(D2-A)` |
| U1 | 3 | 9 | 6 | `GND` |
| U1 | 4 | 9 | 7 | `/LNK` |
| U1 | 6 | 9 | 9 | `/SDA` |
| U1 | 7 | 9 | 10 | `/SCL` |
| U1 | 8 | 9 | 11 | `GND` |
| U1 | 9 | 9 | 12 | `/IRQ` |
| U1 | 13 | 9 | 16 | `GND` |
| U1 | 18 | 9 | 21 | `GND` |
| U1 | 21 | 16 | 23 | `/ENC_A` |
| U1 | 22 | 16 | 22 | `/ENC_B` |
| U1 | 23 | 16 | 21 | `GND` |
| U1 | 28 | 16 | 16 | `GND` |
| U1 | 36 | 16 | 8 | `+3V3` |
| U1 | 38 | 16 | 6 | `GND` |
| U1 | 39 | 16 | 5 | `+5V` |

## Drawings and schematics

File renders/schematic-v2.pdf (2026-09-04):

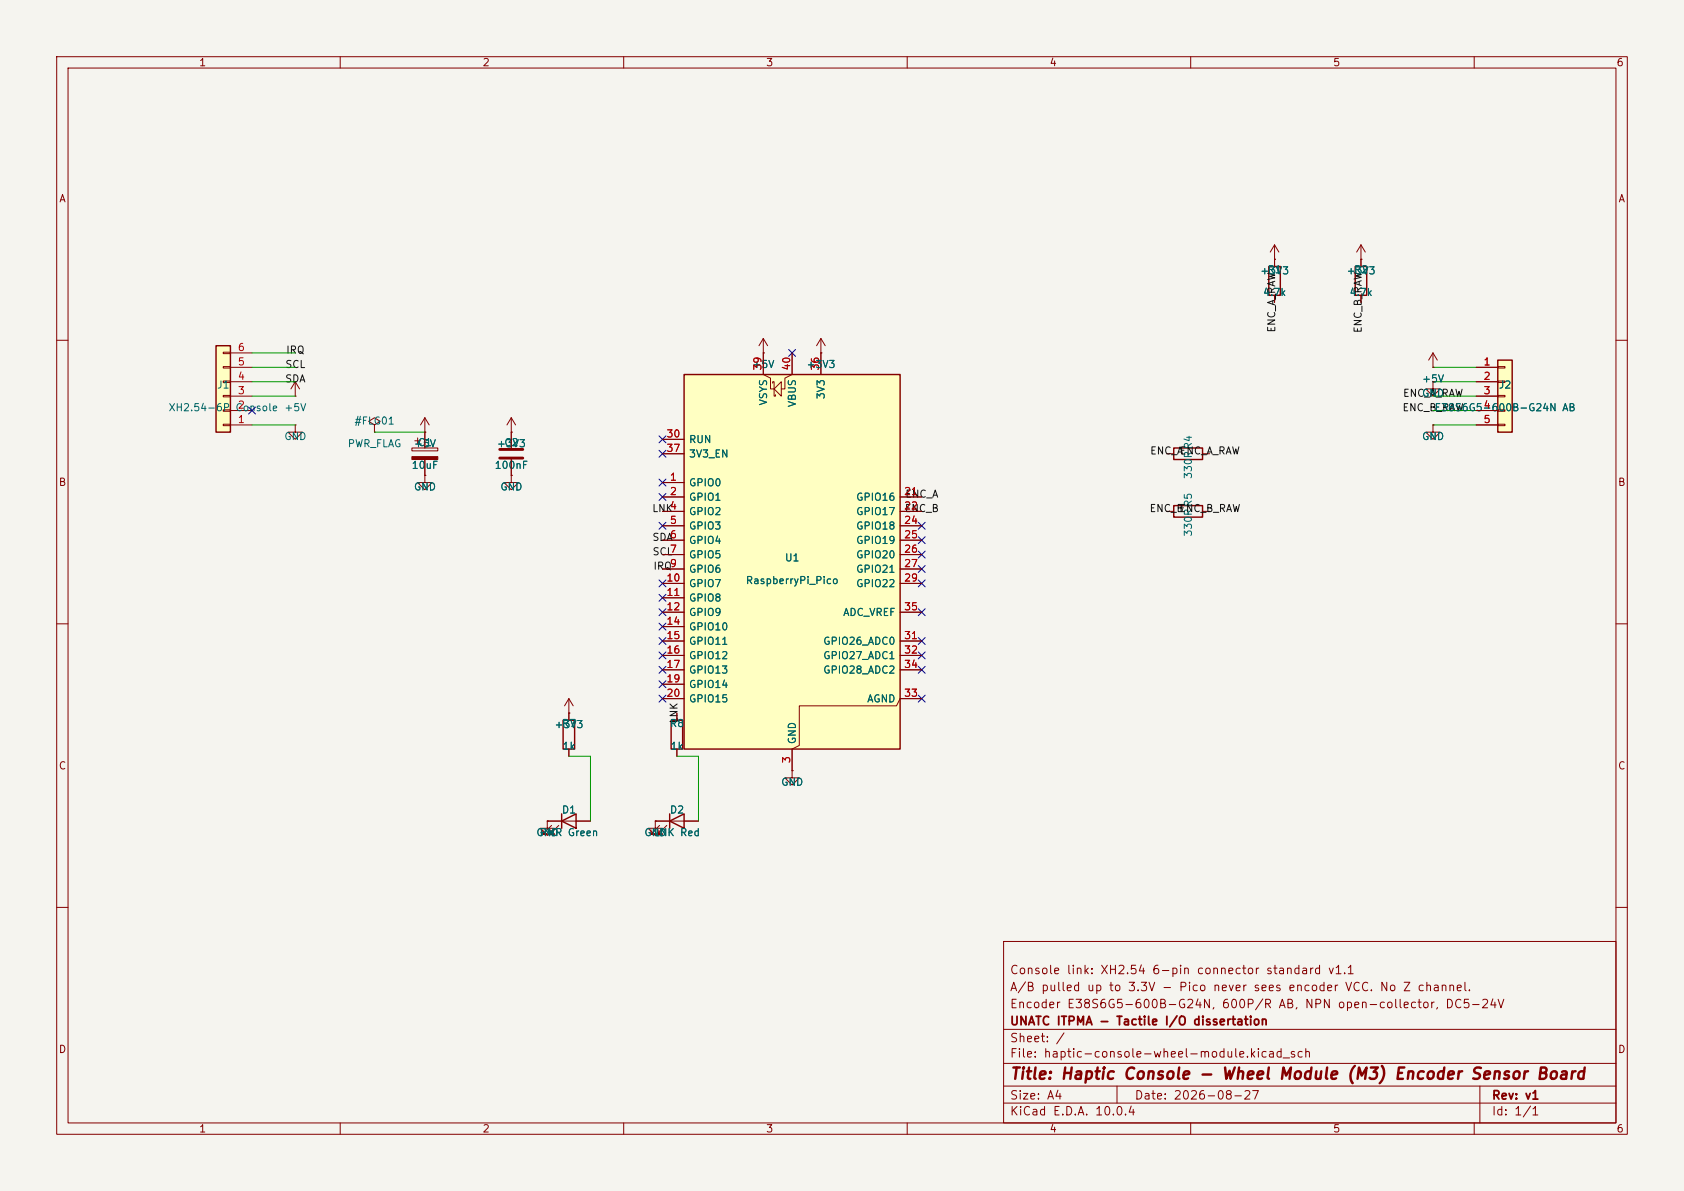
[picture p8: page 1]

Console link: XH2.54 6-pin connector standard v1.1 +3V3

A/B pulled up to 3.3V - Pico never sees encoder VCC. No Z channel.
Encoder E38S6G5-600B-G24N, 600P/R AB, NPN open-collector, DC5-24V
UNATC ITPMA - Tactile I/O dissertation
Sheet: /
File: haptic-console-wheel-module.kicad_sch
Title: Haptic Console - Wheel Module (M3) Encoder Sensor Board

Size: A4 | Rev: v1
KiCad E.D.A. 10.0.4 | Id: 1/1

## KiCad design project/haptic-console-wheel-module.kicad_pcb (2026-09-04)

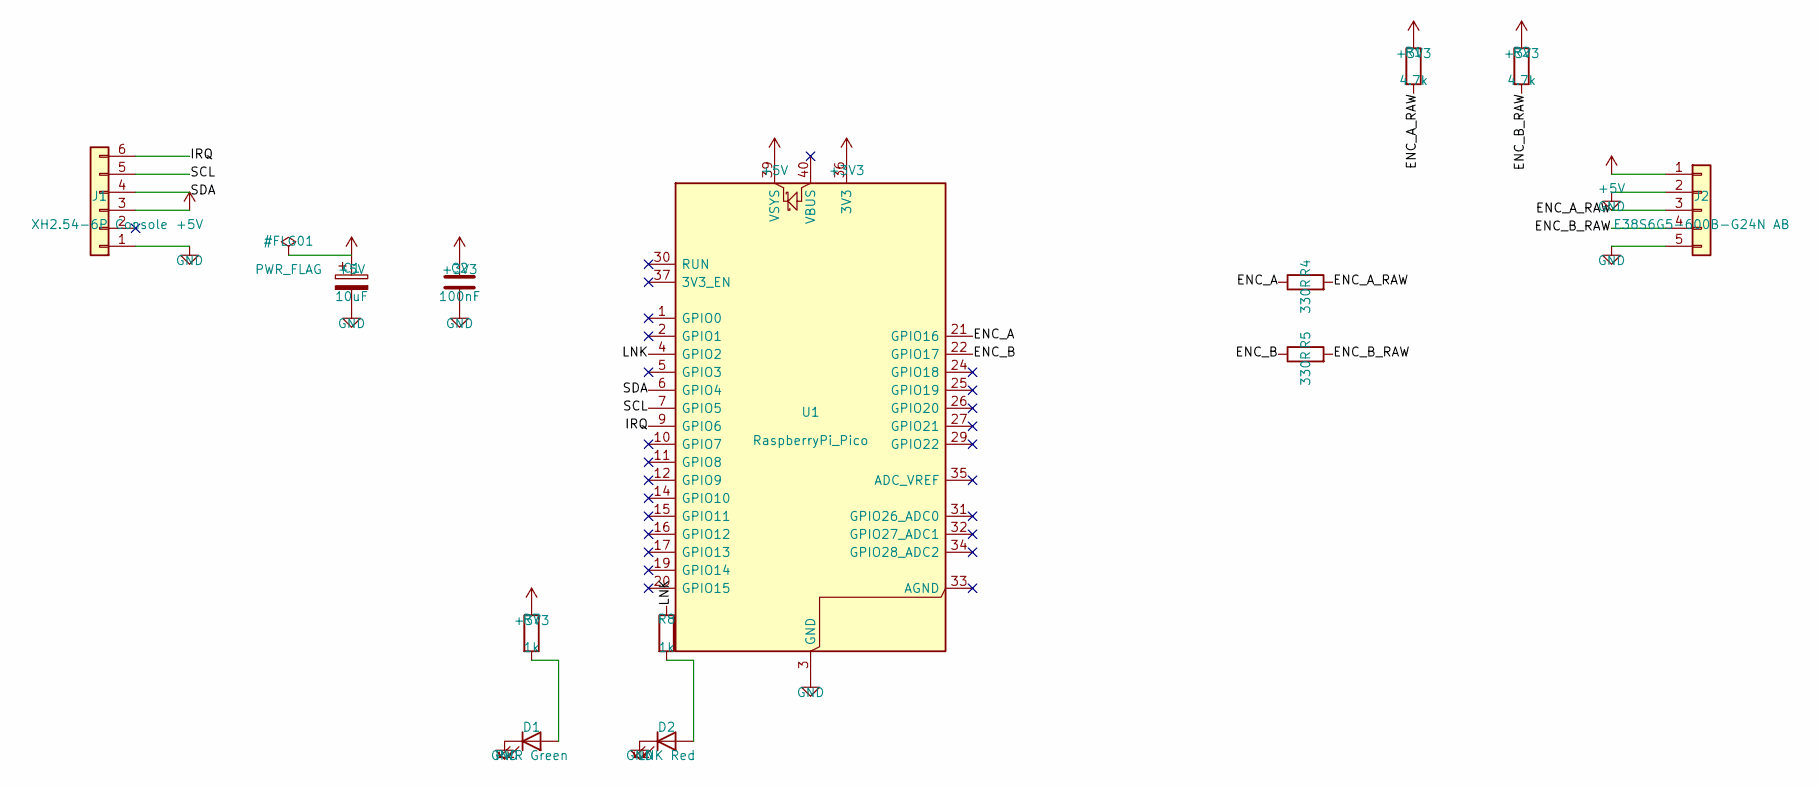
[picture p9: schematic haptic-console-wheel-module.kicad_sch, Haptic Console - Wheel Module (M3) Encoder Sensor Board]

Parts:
C1: 10uF; CP_Radial_D4.0mm_P2.50mm; Voltage 25V
C2: 100nF; C_Disc_D5.0mm_W2.5mm_P5.00mm
D1: PWR Green; LED_D3.0mm
D2: LNK Red; LED_D3.0mm
J1: XH2.54-6P Console; JST_XH_B6B-XH-A_1x06_P2.50mm_Vertical
J2: E38S6G5-600B-G24N AB; PinHeader_1x05_P2.54mm_Vertical
R1, R2: 4.7k; R_Axial_DIN0207_L6.3mm_D2.5mm_P10.16mm_Horizontal
R4, R5: 330R; R_Axial_DIN0207_L6.3mm_D2.5mm_P10.16mm_Horizontal
R7, R8: 1k; R_Axial_DIN0207_L6.3mm_D2.5mm_P10.16mm_Horizontal
U1: RaspberryPi_Pico; RaspberryPi_Pico_Common_THT

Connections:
+3V3: C2.1, R1.1, R2.1, R7.1, U1.36 (3V3)
+5V: C1.1, J1.3, J2.1, U1.39 (VSYS)
/ENC_A: R4.1, U1.21 (GPIO16)
/ENC_A_RAW: J2.3, R1.2, R4.2
/ENC_B: R5.1, U1.22 (GPIO17)
/ENC_B_RAW: J2.4, R2.2, R5.2
/IRQ: J1.6, U1.9 (GPIO6)
/LNK: R8.1, U1.4 (GPIO2)
/SCL: J1.5, U1.7 (GPIO5)
/SDA: J1.4, U1.6 (GPIO4)
GND: C1.2, C2.2, D1.1 (K), D2.1 (K), J1.1, J2.2, J2.5, U1.3 (GND), U1.8 (GND), U1.13 (GND), U1.18 (GND), U1.23 (GND), U1.28 (GND), U1.38 (GND)
unnamed: D1.2 (A), R7.2
unnamed: D2.2 (A), R8.2

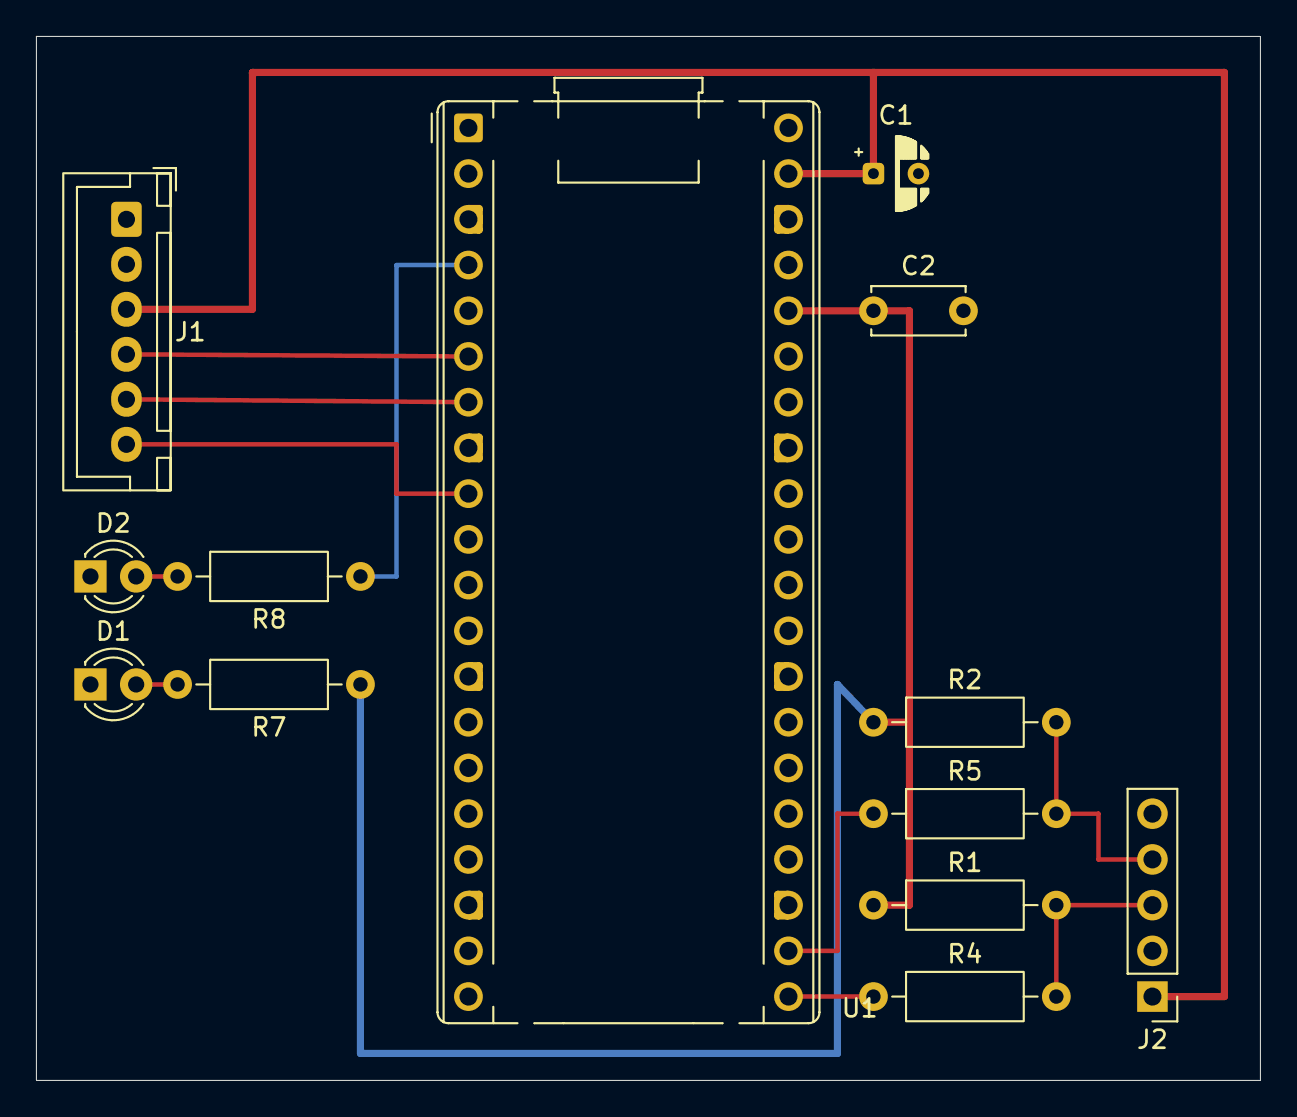
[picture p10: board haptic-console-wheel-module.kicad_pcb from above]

Board: 2 copper layers, 68.0 x 58.0 mm, 13 parts (0 on the bottom side), 13 nets.

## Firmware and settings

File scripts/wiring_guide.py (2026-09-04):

#!/usr/bin/env python3
"""Render docs/stripboard-wiring.html from the layout spec and the built board.

    python3 scripts/wiring_guide.py

Everything the page states about copper -- which strip segment carries which net,
where the segment ends, which pads sit on it -- is read back out of
``project/haptic-console-wheel-module-stripboard.kicad_pcb`` via the engine's own
audit, never from intent.  That is the same rule the layout itself is built on:
derive the net from the pads, and treat the file as the only truth.

Placement boxes and pad coordinates come from a pcbnew dump cached alongside this
script's inputs; the cut list, the link waypoints and the wire colours come from
``scripts/layout.py``.  Re-run this after any rebuild of the board.
"""
import html
import json
import os
import re
import subprocess
import sys

HERE = os.path.dirname(os.path.abspath(__file__))
ROOT = os.path.dirname(HERE)
ENGINE = os.path.expanduser("~/KiCad/kicad-stripboard")
BOARD = os.path.join(ROOT, "project", "haptic-console-wheel-module-stripboard.kicad_pcb")
LAYOUT = os.path.join(HERE, "layout.py")
OUT = os.path.join(ROOT, "docs", "stripboard-wiring.html")
KIPY = ("/Applications/KiCad/KiCad.app/Contents/Frameworks/Python.framework/"
        "Versions/3.9/bin/python3")

CELL = 20                      # px per 2.54 mm hole pitch in the board map
EDGE_LO, EDGE_HI = 0.69, 40.31  # strip copper start/end, in pitch units


# --- inputs ------------------------------------------------------------------

def load_spec():
    import importlib.util
    sys.path.insert(0, ENGINE)
    spec = importlib.util.spec_from_file_location("layout", LAYOUT)
    mod = importlib.util.module_from_spec(spec)
    spec.loader.exec_module(mod)
    return mod


def audit_segments():
    """Strip segments as the engine's audit sees them in the saved board."""
    out = subprocess.run(
        [os.path.join(ENGINE, "build.py"), LAYOUT, BOARD, "--stage", "audit"],
        capture_output=True, text=True, cwd=ROOT).stdout
    segs, totals = [], {}
    for ln in out.splitlines():
        m = re.match(r"(\d+) strip segments, (\d+) holes, (\d+) link tracks", ln)
        if m:
            totals = dict(segments=int(m.group(1)), holes=int(m.group(2)),
                          links=int(m.group(3)))
        m = re.match(r"\s+row\s+(\d+) seg col\s+([\d.]+)\.\.\s*([\d.]+)\s+(\S+)\s*(.*)$", ln)
        if m:
            segs.append(dict(row=int(m.group(1)), x0=float(m.group(2)), x1=float(m.group(3)),
                             net=m.group(4), pads=m.group(5).strip()))
    if not segs:
        sys.exit("audit produced no segments -- is the board built?")
    return segs, totals


def pcb_footprints():
    """Pad grid coordinates and part body outlines, straight out of pcbnew."""
    script = r'''
import pcbnew, json, sys
b = pcbnew.LoadBoard(sys.argv[1]); MM, P = 1e6, 2.54
out = {}
for fp in b.Footprints():
    ref = fp.GetReference()
    if ref.startswith("W"):
        continue
    pads = [dict(n=p.GetNumber(), col=round(p.GetPosition().x/MM/P, 3),
                 row=round(p.GetPosition().y/MM/P, 3), net=p.GetNetname())
            for p in fp.Pads()]
    # Draw the part's real body (the *Fab outline), not its courtyard.  The
    # courtyard is a keep-out and runs well past the part -- on the Pico it is
    # ~1.5 mm proud at each end, enough to cover the whole neighbouring strip
    # and make row 1 look like it is underneath the module when it is not.
    xs, ys = [], []
    for it in fp.GraphicalItems():
        # shapes only: the *Fab layers also carry a REF** text item, which would
        # drag the box out to wherever the designator happens to sit
        if not isinstance(it, pcbnew.PCB_SHAPE):
            continue
        if it.GetLayer() not in (pcbnew.F_Fab, pcbnew.B_Fab):
            continue
        # Polygons on *Fab mark features, not the outline -- on the Pico it is
        # the USB shell, which overhangs the module's top edge by 1.3 mm.  That
        # shell rides 8.5 mm up in the air on the socket headers and obstructs
        # nothing, so drawing it would put the module back over row 1.
        if it.GetShapeStr() == "Polygon":
            continue
        bb, half = it.GetBoundingBox(), it.GetWidth() // 2
        # Read the ints out *now*.  GetBoundingBox() hands back a temporary
        # BOX2I proxy; holding on to one and merging others into it returns
        # garbage, the same SWIG lifetime trap the engine documents.
        xs += [bb.GetLeft() + half, bb.GetRight() - half]
        ys += [bb.GetTop() + half, bb.GetBottom() - half]
    if xs:
        box = [min(xs), min(ys), max(xs), max(ys)]
    else:                                  # no fab outline -- fall back
        cy = fp.GetCourtyard(pcbnew.F_CrtYd)
        if cy.OutlineCount() == 0:
            cy = fp.GetCourtyard(pcbnew.B_CrtYd)
        r = cy.BBox()
        box = [r.GetLeft(), r.GetTop(), r.GetRight(), r.GetBottom()]
    out[ref] = dict(value=fp.GetValue(), fp=str(fp.GetFPIDAsString()),
                    pads=sorted(pads, key=lambda d: (len(d["n"]), d["n"])),
                    box=[round(v/MM/P, 3) for v in box])
print(json.dumps(out))
'''
    r = subprocess.run([KIPY, "-c", script, BOARD], capture_output=True, text=True)
    return json.loads(r.stdout)


# --- net classification ------------------------------------------------------

POWER = {"+5V", "+3V3"}
BUS = {"/SDA", "/SCL", "/IRQ"}


def net_class(net):
    if not net:
        return "spare"
    if net.startswith("unconnected-"):
        return "free"
    if net in POWER:
        return "power"
    if net == "GND":
        return "gnd"
    if net in BUS:
        return "i2c"
    return "signal"


def net_label(net):
    """`unconnected-(U1-GPIO7-Pad10)` reads as `U1.10 GPIO7` on a bench."""
    m = re.match(r"unconnected-\((\w+)-(.+)-Pad(\w+)\)$", net or "")
    if m:
        return f"{m.group(1)}.{m.group(3)} {m.group(2)}"
    return net or "—"


# --- board map ---------------------------------------------------------------

def build_map(spec, segs, fps):
    cuts_by_row = {}
    for c, r in spec.cuts:
        cuts_by_row.setdefault(r, []).append(c)

    seg_net = {}
    for s in segs:
        seg_net[(s["row"], round(s["x0"], 2))] = s

    W = 41 * CELL
    GL, GT = 26, 20                 # gutters for the row / column rulers
    o = [f'<svg viewBox="{-GL} {-GT} {W + GL + 8} {W + GT + 8}" role="img" '
         f'aria-label="Board map: 40 by 40 hole Veroboard, strips running left to right">']
    o.append('<defs>'
             f'<pattern id="holes" x="{CELL//2}" y="{CELL//2}" width="{CELL}" height="{CELL}" '
             'patternUnits="userSpaceOnUse">'
             f'<circle class="hole" cx="{CELL//2}" cy="{CELL//2}" r="2.3"/></pattern></defs>')
    o.append(f'<rect class="board" x="0" y="0" width="{W}" height="{W}" rx="6"/>')

    # strip segments, coloured by the net the audit found on them
    o.append('<g class="strips">')
    for row in range(1, spec.grid.rows + 1):
        bounds = [EDGE_LO]
        for c in sorted(cuts_by_row.get(row, [])):
            bounds += [c - 0.5, c + 0.5]
        bounds.append(EDGE_HI)
        for i in range(0, len(bounds), 2):
            x0, x1 = bounds[i], bounds[i + 1]
            s = seg_net.get((row, round(x0, 2)))
            net = s["net"] if s else ("+5V" if row == 2 else "")
            cls = net_class(net)
            pads = s["pads"] if s else ("link-fed rail" if row == 2 else "")
            title = (f"row {row}, cols {int(x0 + 0.5)}–{int(x1)} — "
                     f"{net_label(net) if net else 'spare, no net'}"
                     + (f" — {pads}" if pads else ""))
            o.append(
                f'<g class="seg seg-{cls}" data-net="{html.escape(net or "")}" '
                f'data-row="{row}"><title>{html.escape(title)}</title>'
                f'<rect x="{x0 * CELL:.1f}" y="{(row - 0.375) * CELL:.1f}" '
                f'width="{(x1 - x0) * CELL:.1f}" height="{0.75 * CELL:.1f}" rx="3"/></g>')
    o.append('</g>')

    # holes, as one tiled pattern rather than 1600 circles
    o.append(f'<rect class="holefill" x="{0.5 * CELL}" y="{0.5 * CELL}" '
             f'width="{40 * CELL}" height="{40 * CELL}" fill="url(#holes)"/>')

    # link wires, along the gutter waypoints the copper actually follows
    o.append('<g class="links">')
    for i, lk in enumerate(spec.links, 1):
        if len(lk.points) < 2:
            continue
        pts = " ".join(f"{c * CELL:.1f},{r * CELL:.1f}" for c, r in lk.points)
        colour = spec.wire_colors.get(lk.net, "white")
        kind = "tap" if not lk.wire else "wire"
        o.append(f'<polyline class="link link-{colour} link-{kind}" data-net="{html.escape(lk.net)}" '
                 f'points="{pts}"><title>{html.escape(lk.net)} link '
                 f'{"(solder tap on the GND spine)" if not lk.wire else ""}</title></polyline>')
    o.append('</g>')

    # component outlines
    o.append('<g class="parts">')
    for ref, fp in sorted(fps.items()):
        x0, y0, x1, y1 = fp["box"]
        o.append(f'<g class="part" data-ref="{ref}"><title>{ref} — '
                 f'{html.escape(fp["value"])}</title>'
                 f'<rect x="{x0 * CELL:.1f}" y="{y0 * CELL:.1f}" '
                 f'width="{(x1 - x0) * CELL:.1f}" height="{(y1 - y0) * CELL:.1f}" rx="4"/>'
                 f'<text x="{(x0 + x1) / 2 * CELL:.1f}" '
                 f'y="{(y0 * CELL + 11) if (y1 - y0) > 3 else ((y0 + y1) / 2 * CELL):.1f}" '
                 f'dy="0.32em">{ref}</text></g>')
    o.append('</g>')

    # cut markers
    o.append('<g class="cuts">')
    for c, r in sorted(spec.cuts, key=lambda t: (t[1], t[0])):
        x, y = c * CELL, r * CELL
        d = 5.0
        o.append(f'<g class="cut" data-cut="{c},{r}"><title>cut column {c}, row {r}</title>'
                 f'<circle cx="{x}" cy="{y}" r="7"/>'
                 f'<path d="M{x - d} {y - d}L{x + d} {y + d}M{x + d} {y - d}L{x - d} {y + d}"/></g>')
    o.append('</g>')

    # rulers -- you count rows and columns constantly at the bench
    o.append('<g class="ruler">')
    for c in range(1, spec.grid.cols + 1):
        cls = "tick major" if c % 5 == 0 or c == 1 else "tick"
        o.append(f'<text class="{cls}" x="{c * CELL}" y="-7">{c}</text>')
    for r in range(1, spec.grid.rows + 1):
        cls = "tick major" if r % 5 == 0 or r == 1 else "tick"
        o.append(f'<text class="{cls} rowtick" x="-9" y="{r * CELL}" dy="0.32em">{r}</text>')
    o.append('</g>')

    o.append('</svg>')
    return "\n".join(o)


# --- page --------------------------------------------------------------------

CSS = """
:root {
  --bg:#f3ede2; --surface:#fffdf8; --surface-2:#ece3d3; --ink:#241c15;
  --muted:#6b5f4f; --border:#d8cbb2; --copper:#b1662f;
  --power:#a63b2e; --power-bg:#f6e2dd;
  --gnd:#4a4640;   --gnd-bg:#e6e2da;
  --i2c:#8a5a17;   --i2c-bg:#f1e2c4;
  --signal:#235e78;--signal-bg:#dfeaef;
  --free:#8d8272;  --free-bg:#e9e4da;
  --hl:#ffd977; --cut:#b03024;
  --board:#c9a173; --hole:#6d4b28; --spare:#b98f5f;
  --w-red:#c0392b; --w-blue:#2b6ca3; --w-yellow:#cf9a12; --w-green:#3d8b4a;
  --shadow:0 1px 2px rgba(36,28,21,.06), 0 8px 24px rgba(36,28,21,.05);
}
@media (prefers-color-scheme: dark) {
  :root:not([data-theme="light"]) {
    --bg:#17130f; --surface:#211a14; --surface-2:#2a2119; --ink:#f1e7d7;
    --muted:#a6957d; --border:#3c3025; --copper:#e0a868;
    --power:#e2897b; --power-bg:#3a221e;
    --gnd:#cfc7b8;  --gnd-bg:#2c2822;
    --i2c:#e8c37e;  --i2c-bg:#3a2e15;
    --signal:#8fc4de;--signal-bg:#1c2f37;
    --free:#8b7f6d; --free-bg:#241d17;
    --hl:#6a5116; --cut:#e2705f;
    --board:#6b4b2c; --hole:#241a10; --spare:#7d5a35;
    --w-red:#e0705f; --w-blue:#6fa8d6; --w-yellow:#e3b445; --w-green:#6bbd78;
    --shadow:0 1px 2px rgba(0,0,0,.3), 0 12px 32px rgba(0,0,0,.35);
  }
}
:root[data-theme="dark"] {
  --bg:#17130f; --surface:#211a14; --surface-2:#2a2119; --ink:#f1e7d7;
  --muted:#a6957d; --border:#3c3025; --copper:#e0a868;
  --power:#e2897b; --power-bg:#3a221e;
  --gnd:#cfc7b8;  --gnd-bg:#2c2822;
  --i2c:#e8c37e;  --i2c-bg:#3a2e15;
  --signal:#8fc4de;--signal-bg:#1c2f37;
  --free:#8b7f6d; --free-bg:#241d17;
  --hl:#6a5116; --cut:#e2705f;
  --board:#6b4b2c; --hole:#241a10; --spare:#7d5a35;
  --w-red:#e0705f; --w-blue:#6fa8d6; --w-yellow:#e3b445; --w-green:#6bbd78;
  --shadow:0 1px 2px rgba(0,0,0,.3), 0 12px 32px rgba(0,0,0,.35);
}
* { box-sizing:border-box; }
body { margin:0; background:var(--bg); color:var(--ink); line-height:1.5;
  font-family:ui-sans-serif, system-ui, -apple-system, "Segoe UI", sans-serif;
  padding:0 0 6rem; }
.wrap { max-width:1080px; margin:0 auto; padding:0 1.5rem; }
code, .mono { font-family:ui-monospace, SFMono-Regular, Menlo, monospace; }
code { font-size:.9em; background:var(--surface-2); padding:.05rem .3rem; border-radius:3px; }
a { color:var(--copper); text-underline-offset:2px; }

header.page-head { padding-top:3rem; padding-bottom:1.75rem; margin-bottom:1.5rem;
  border-bottom:3px solid var(--copper); display:flex; flex-direction:column; gap:.5rem; }
.eyebrow { font-family:ui-monospace, monospace; font-size:.72rem; letter-spacing:.14em;
  text-transform:uppercase; color:var(--copper); }
h1 { font-weight:800; font-size:clamp(2rem,5vw,2.7rem); margin:0; text-wrap:balance; }
.dek { color:var(--muted); font-size:1rem; max-width:68ch; margin:0; }
h2 { font-weight:700; font-size:1.4rem; margin:0 0 .25rem; scroll-margin-top:5.5rem;
  text-wrap:balance; }
h3 { font-weight:600; font-size:1.02rem; margin:0; }
section { margin-bottom:3rem; scroll-margin-top:4.5rem; }
.section-intro { color:var(--muted); font-size:.92rem; max-width:68ch; margin:0 0 1.25rem; }

.toolbar { position:sticky; top:0; z-index:20; border-bottom:1px solid var(--border);
  background:color-mix(in srgb, var(--bg) 92%, transparent); backdrop-filter:blur(8px); }
.toolbar-in { max-width:1080px; margin:0 auto; padding:.6rem 1.5rem; display:flex;
  gap:.75rem; align-items:center; flex-wrap:wrap; }
.toolbar nav { display:flex; gap:.15rem; flex-wrap:wrap; }
.toolbar nav a { font-size:.78rem; color:var(--muted); text-decoration:none;
  padding:.25rem .5rem; border-radius:5px; }
.toolbar nav a:hover, .toolbar nav a:focus-visible { background:var(--surface-2); color:var(--ink); }
.grow { flex:1 1 auto; }
#q { font-family:ui-monospace, monospace; font-size:.8rem; padding:.35rem .6rem;
  min-width:11rem; border:1px solid var(--border); border-radius:6px;
  background:var(--surface); color:var(--ink); }
.btn { font-size:.76rem; padding:.3rem .6rem; border:1px solid var(--border);
  border-radius:6px; background:var(--surface); color:var(--muted); cursor:pointer; }
.btn:hover { color:var(--ink); }
:focus-visible { outline:2px solid var(--copper); outline-offset:2px; }

.stats { display:grid; grid-template-columns:repeat(auto-fit,minmax(112px,1fr)); gap:.6rem;
  margin-bottom:1.75rem; }
.stat { background:var(--surface); border:1px solid var(--border); border-radius:8px;
  box-shadow:var(--shadow); padding:.7rem .85rem; }
.stat b { display:block; font-family:ui-monospace, monospace; font-size:1.25rem;
  font-weight:700; font-variant-numeric:tabular-nums; }
.stat span { font-size:.7rem; color:var(--muted); text-transform:uppercase;
  letter-spacing:.08em; }

.callout { background:var(--surface); border:1px solid var(--border);
  border-left:4px solid var(--copper); border-radius:8px; box-shadow:var(--shadow);
  padding:.9rem 1.1rem; margin-bottom:1.5rem; font-size:.9rem; color:var(--muted); }
.callout strong { color:var(--ink); }
.callout.warn { border-left-color:var(--cut); }
.callout p { margin:.5rem 0 0; }
.callout p:first-child { margin-top:0; }

/* --- board map --- */
.map-frame { background:var(--surface); border:1px solid var(--border); border-radius:10px;
  box-shadow:var(--shadow); padding:1rem; overflow-x:auto; }
.map-frame svg { display:block; width:100%; min-width:620px; height:auto; }
.board { fill:var(--board); }
.hole { fill:var(--hole); opacity:.45; }
.seg rect { stroke-width:.6; }
.seg-power  rect { fill:var(--power);  stroke:var(--power);  fill-opacity:.55; }
.seg-gnd    rect { fill:var(--gnd);    stroke:var(--gnd);    fill-opacity:.5; }
.seg-i2c    rect { fill:var(--i2c);    stroke:var(--i2c);    fill-opacity:.55; }
.seg-signal rect { fill:var(--signal); stroke:var(--signal); fill-opacity:.55; }
.seg-free   rect { fill:var(--spare);  stroke:var(--spare);  fill-opacity:.62; }
.seg-spare  rect { fill:var(--spare);  stroke:var(--spare);  fill-opacity:.48; }
.seg:hover rect { fill-opacity:.9; }
.ruler text { font:9px ui-monospace, monospace; fill:var(--muted); text-anchor:middle;
  opacity:.65; }
.ruler .major { fill:var(--ink); opacity:.9; font-weight:700; }
.ruler .rowtick { text-anchor:end; }
.cut circle { fill:var(--surface); stroke:var(--cut); stroke-width:.8; }
.cut path { stroke:var(--cut); stroke-width:2.4; stroke-linecap:round; }
.link { fill:none; stroke-width:3.4; stroke-linecap:round; stroke-linejoin:round; opacity:.95; }
.link-red { stroke:var(--w-red); } .link-blue { stroke:var(--w-blue); }
.link-yellow { stroke:var(--w-yellow); } .link-green { stroke:var(--w-green); }
.link-tap { stroke-width:2.2; stroke-dasharray:3 3; }
.part rect { fill:var(--surface); fill-opacity:.82; stroke:var(--ink); stroke-opacity:.55;
  stroke-width:1.2; }
.part text { font:700 11px ui-monospace, monospace; fill:var(--ink); text-anchor:middle; }
svg .dim { opacity:.12; }
.map-legend { display:flex; flex-wrap:wrap; gap:.45rem; margin-top:.9rem; }
.chip { font-family:ui-monospace, monospace; font-size:.74rem; padding:.28rem .7rem;
  border:1px solid var(--border); border-radius:999px; background:var(--surface);
  color:var(--muted); cursor:pointer; display:inline-flex; align-items:center; gap:.4rem; }
.chip[aria-pressed="true"] { background:var(--copper); border-color:var(--copper); color:var(--bg); }
.chip .sw { width:.62rem; height:.62rem; border-radius:2px; flex:none; }
.sw-power { background:var(--power); } .sw-gnd { background:var(--gnd); }
.sw-i2c { background:var(--i2c); } .sw-signal { background:var(--signal); }
.sw-free { background:var(--spare); }
.sw-red { background:var(--w-red); } .sw-blue { background:var(--w-blue); }
.sw-yellow { background:var(--w-yellow); } .sw-green { background:var(--w-green); }
.sw-cut { background:var(--cut); }

/* --- tables --- */
.tbl-frame { background:var(--surface); border:1px solid var(--border); border-radius:10px;
  box-shadow:var(--shadow); overflow-x:auto; }
table { width:100%; border-collapse:collapse; font-size:.82rem; }
thead th { position:sticky; top:0; background:var(--surface-2); text-align:left;
  font-size:.7rem; letter-spacing:.07em; text-transform:uppercase; color:var(--muted);
  padding:.5rem .75rem; border-bottom:1px solid var(--border); white-space:nowrap; }
tbody td { padding:.4rem .75rem; border-top:1px solid var(--border); vertical-align:top; }
tbody tr:first-child td { border-top:none; }
tbody tr:hover { background:var(--surface-2); }
td.n, th.n { font-family:ui-monospace, monospace; font-variant-numeric:tabular-nums;
  white-space:nowrap; }
td.net { font-family:ui-monospace, monospace; font-weight:600; white-space:nowrap; }
td.net.power { color:var(--power); } td.net.gnd { color:var(--gnd); }
td.net.i2c { color:var(--i2c); } td.net.signal { color:var(--signal); }
td.net.free, td.net.spare { color:var(--free); font-weight:400; }
tr.keep td { background:var(--gnd-bg); }
tr.isolate td { background:var(--power-bg); }
tr.dim { opacity:.25; }
.tag { font-family:ui-monospace, monospace; font-size:.66rem; padding:.05rem .4rem;
  border-radius:3px; border:1px solid var(--border); color:var(--muted); white-space:nowrap; }

/* --- checklist --- */
.progress { font-family:ui-monospace, monospace; font-size:.76rem; color:var(--muted);
  display:flex; align-items:center; gap:.5rem; }
.progress .bar { width:6rem; height:5px; border-radius:3px; background:var(--surface-2);
  overflow:hidden; }
.progress .bar i { display:block; height:100%; width:0; background:var(--copper);
  transition:width .2s; }
.steps { list-style:none; margin:0; padding:0; display:flex; flex-direction:column; gap:.5rem;
  counter-reset:step; }
.steps li { background:var(--surface); border:1px solid var(--border); border-radius:8px;
  box-shadow:var(--shadow); padding:.7rem .95rem; display:flex; gap:.75rem;
  align-items:flex-start; font-size:.88rem; }
.steps li::before { counter-increment:step; content:counter(step);
  font-family:ui-monospace, monospace; font-size:.7rem; font-weight:700; color:var(--copper);
  border:1px solid var(--border); border-radius:5px; padding:.1rem .4rem; margin-top:.1rem;
  flex:none; }
.steps input { margin-top:.28rem; accent-color:var(--copper); flex:none; }
.steps li.done { opacity:.5; }
.steps li.done .step-body { text-decoration:line-through; text-decoration-color:var(--muted); }
.step-body strong { display:block; }
.step-body span { color:var(--muted); font-size:.84rem; }
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

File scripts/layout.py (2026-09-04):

"""Stripboard layout for the Wheel Module (M3) encoder sensor board.

Pure data.  The engine that turns it into copper lives in
``~/KiCad/kicad-stripboard`` and is shared with the other board projects:

    ~/KiCad/kicad-stripboard/build.py \
        scripts/layout.py \
        project/haptic-console-wheel-module-stripboard.kicad_pcb \
        --from project/haptic-console-wheel-module-perfboard.kicad_pcb

Grid: col c -> x = c * 2.54 mm, row r -> y = r * 2.54 mm; cols 1..40, rows 1..40,
board 104.14 mm square with a one-hole margin.  Strips run horizontally on B.Cu,
link wires on F.Cu.  Human-readable build guide: ``docs/stripboard-wiring.md``
(and ``docs/stripboard-wiring.html``).

The grid is the size of the stock the board is actually built on -- a 40 x 40
hole Veroboard.  The circuit occupies cols 1..28 / rows 1..28 in the top-left;
everything beyond that is spare board.  Strips still run the *full* width, so the
right-hand end of every row is live copper continuous with the part of the row
the circuit uses.
"""

import os
from stripboard import BoardSpec, Grid, Link, Placement

GRID = Grid(cols=40, rows=40)

# --- U1, the Pico ------------------------------------------------------------
# Pin 1 at (col 9, row 2), unrotated.  Left pins 1..20 run down col 9 on rows
# 2..21; right pins 21..40 run back up col 16.
#
# Row 1 is left empty on purpose.  The module body is 51 mm for 19 pin pitches
# (48.26 mm), so it overhangs its end rows by 1.37 mm: the body edge sits at
# y = 3.71 mm and a row-1 hole's copper ends at 3.29 mm.  0.42 mm of daylight,
# and only usable at all because the Pico is socketed on 8.5 mm headers and
# overhangs in mid-air.  Nothing is soldered there.
PICO_COL_L, PICO_COL_R, PICO_ROW0 = 9, 16, 2


def pico_row(pin):
    return PICO_ROW0 + (pin - 1 if pin <= 20 else 40 - pin)


# --- What each row carries ---------------------------------------------------
# Documentation, not an input: the engine derives every strip's net from the
# pads that actually land on it.  Kept because it is how the layout was reasoned
# about, and because a mismatch between this and the audit output is a signal.
#
# Rows 4/14/19 are GND on BOTH sides of the Pico (pins 3/38, 13/28, 18/23), so
# leaving them uncut buys six GND connections and the GND bus for free.  Row 9
# is GND (pin 8) on the left and AGND (pin 33) on the right and MUST be cut --
# AGND is a design-invariant no-connect, and tying it to GND re-creates the
# power_out/power_out ERC violation recorded in CLAUDE.md.
ROW_NET = {
    3:  "+5V",          # U1.39 VSYS + C1.1 (right segment) -- the +5V rail
    4:  "GND",          # U1.3 / U1.38 + J1.1    -- uncut
    5:  "/LNK",         # U1.4 (middle segment); left-of-cut = J1.2, no-connect
    6:  "+3V3",         # U1.36 (right);         left-of-cut = J1.3 +5V stub
    7:  "/SDA",         # U1.6  + J1.4
    8:  "/SCL",         # U1.7  + J1.5
    9:  "GND",          # U1.8 middle; AGND right (isolated); J1.6 stub left
    10: "/IRQ",         # U1.9  + link from J1.6
    14: "GND",          # U1.13 / U1.28          -- uncut
    19: "GND",          # U1.18 / U1.23          -- uncut
    20: "/ENC_B",       # U1.22 (right segment)
    21: "/ENC_A",       # U1.21 (right);         J2.5 stub right of the col-26 cut
    22: "/ENC_B_RAW",
    23: "/ENC_A_RAW",
    24: "+3V3",         # R1.1 R2.1 C2.1;        J2.2 stub right of the col-27 cut
    25: "+5V",          # right of the col-12 cut (J2.1); left = Net-(D1-A)
    26: "GND",
    27: "Net-(D2-A)",
    28: "/LNK",
}

# --- Cuts --------------------------------------------------------------------
MAIN_CUT_COL = 12       # between the Pico's two pin columns
LEFT_CUT_COL = 5        # between J1 and the Pico

CUTS = (
    # main cut: every Pico row except the three GND rows, plus row 25
    [(MAIN_CUT_COL, r) for r in range(2, 22) if r not in (4, 14, 19)]
    + [(MAIN_CUT_COL, 25)]
    # left cut: the rows where J1's pin order disagrees with the Pico's
    + [(LEFT_CUT_COL, r) for r in (5, 6, 9)]
    # right cuts: isolate J2's two GND pins from /ENC_A and +3V3
    + [(26, 21), (27, 24)]
)

# --- Footprints --------------------------------------------------------------
# Every two-pad part stands on end so its pads land on two different rows.  Lying
# flat -- which is what the point-to-point perfboard layout does -- would put both
# pads on the same strip and short the part out.
RV254 = "Resistor_THT:R_Axial_DIN0207_L6.3mm_D2.5mm_P2.54mm_Vertical"
RV508 = "Resistor_THT:R_Axial_DIN0207_L6.3mm_D2.5mm_P5.08mm_Vertical"
CP250 = "wheel-module:CP_Radial_D4.0mm_P2.50mm"    # polarised: pad 1 = +, pad 2 = -
CD500 = "Capacitor_THT:C_Disc_D5.0mm_W2.5mm_P5.00mm"

PLACE = {
    # pad 1 goes exactly on (col, row); footprint=None keeps the existing one
    "U1": Placement(9, 2, 0),
    "J1": Placement(2, 4, 270),        # pins 1..6 -> rows 4..8.92 (2.50 mm pitch)
    "J2": Placement(28, 25, 180),      # pins 1..5 -> rows 25, 24, 23, 22, 21
    # encoder cluster, right region, >= 2 columns apart (courtyards, not holes,
    # decide spacing)
    "R5": Placement(18, 20, 270, RV508),   # /ENC_B r20 -> /ENC_B_RAW r22
    "R4": Placement(20, 21, 270, RV508),   # /ENC_A r21 -> /ENC_A_RAW r23
    "R2": Placement(22, 24, 90, RV508),    # +3V3   r24 -> /ENC_B_RAW r22
    "R1": Placement(24, 24, 90, RV254),    # +3V3   r24 -> /ENC_A_RAW r23
    "C2": Placement(26, 24, 270, CD500),   # +3V3   r24 -> GND         r26
    # C1 is the D4x7 electrolytic, drawn project-local because no stock CP_Radial
    # pairs a 4 mm can with a 2.50 mm pitch, and only 2.50 keeps the pads on the
    # 2.54 grid.  Its 4.59 mm courtyard clears U1 by 0.18 mm here; the 5 mm can
    # did not, which is the whole reason the accurate body is worth drawing.
"C1": Placement(18, 3, 270, CP250),    # +5V    r3  -> GND         r4  (+ on r3)
    # LED chain, left region
    "R7": Placement(2, 24, 270, RV254),    # +3V3   r24 -> Net-(D1-A)  r25
    "D1": Placement(4, 26, 90),            # GND    r26 -> Net-(D1-A)  r25
    "D2": Placement(6, 26, 270),           # GND    r26 -> Net-(D2-A)  r27
    "R8": Placement(2, 28, 90, RV254),     # /LNK   r28 -> Net-(D2-A)  r27
}

# R4 and R5 are the nicest part of this layout: they reach from the Pico's
# /ENC_A and /ENC_B pins straight down to the _RAW rows with no link wire at
# all, so the two noise-sensitive nets are pure copper.
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

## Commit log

2026-08-27 Wheel Module (M3) encoder sensor board: initial schematic
    Pico-based I2C sensor module reading a 600 P/R optical encoder via the
    1:1 GT2 belt drive, exposed to the Teensy master over the XH2.54 6-pin
    connector standard v1.1.
    The encoder is NPN open-collector rated DC 5-24V, so A/B/Z are pulled up
    to 3.3V (R1-R3, 4.7k) with 220R series limiters (R4-R6) into the Pico.
    The high level is set by the pull-up rail, not the encoder supply, so the
    logic side is safe whether the encoder runs at 5V or 12V.
    J1 pin 2 (hub 3.3V) is left unconnected per the connector standard; the
    Pico takes 5V into VSYS and provides its own 3.3V reference.
    ERC 0 errors / 0 warnings. Netlist exported and verified node b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
    [haptic-console-wheel-module.kicad_sch]
2026-08-27 Update schematic and renders
    [haptic-console-wheel-module.kicad_sch]
2026-08-28 Wheel Module (M3): perfboard layout, 0 DRC errors
    Adds project/haptic-console-wheel-module-perfboard.kicad_pcb - a 28x28 hole
    2.54mm perfboard placement (71.12 x 71.12 mm cut) for the encoder sensor board.
    Layout puts the Pico vertically down the centre (pin 1 at col 9, row 4), J1
    console connector on the left edge and J2 encoder connector on the right, so
    the 2 m encoder cable and the console harness leave on opposite sides. Signals
    were placed to land on the same grid row as their Pico pin wherever possible:
    GND row 6, SDA row 9, SCL row 10 and ENC_A row 23 are straight single-row
    jumpers. Only IRQ and ENC_B need a one-row diagonal hop.
    Verified by recomputing every pad's world position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
    [haptic-console-wheel-module-perfboard.kicad_pcb]
2026-08-28 Wheel Module (M3): manufactured PCB placement and routing
    Adds project/haptic-console-wheel-module.kicad_pcb - the fabricated 2-layer
    board, separate from the perfboard file. 68 x 58 mm, all 13 components THT.
    Placement mirrors the perfboard's logic: Pico vertical down the centre, J1
    console on the left edge, J2 encoder on the right, so the 2 m encoder cable
    and the console harness leave on opposite sides. The right-hand passives sit
    at x=46.5, shifted 1.5 mm clear of the Pico footprint's courtyard, which
    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
    [haptic-console-wheel-module.kicad_pcb]
2026-08-28 Wheel Module (M3): GND pour, board fully connected (0 DRC errors)
    Adds a filled GND zone on B.Cu (3270 mm2 of copper on a 68 x 58 mm board).
    All 14 GND pads are through-hole and tie straight into the plane, so GND
    needs no routed traces at all.
    DRC is now clean: 0 errors, 0 shorts and - importantly - 0 unconnected
    items. Every net is connected. The 6 remaining warnings are cosmetic: five
    lib_footprint_mismatch (footprint copies written by the placement tool differ
    cosmetically from the stock library) and one silk_over_copper on U1's
    reference text.
    Tooling note: the zone had to be built through pcbnew rather than the MCP
    pcb_add_zone tool. That tool returned a UUID but produced no zone pcb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
    [haptic-console-wheel-module.kicad_pcb]
2026-08-28 Wheel Module (M3): renders and Gerber set for the fabricated board
    Adds top and bottom 3D renders, and project/haptic-console-wheel-module-gerbers.zip
    containing the standard fabrication set: F_Cu, B_Cu, both mask and silkscreen
    layers, paste, Edge_Cuts, the .gbrjob and the drill file (11 files).
    Exported with kicad-cli using --no-protel-ext, matching the naming the control
    unit board used.
2026-08-28 Wheel Module (M3): document the fabricated board and its tooling traps
    README status now records the fabricated PCB as complete (0 DRC errors, 0
    shorts, 0 unconnected) and explains the two back-layer runs and the offset
    +3V3 spine.
    CLAUDE.md gains a fabricated-PCB section covering five traps that each cost
    real time:
    - Pad coordinates must come from pcbnew, never a regex over the S-expression.
    A hand-rolled parser reported R1 and R5 swapped relative to reality and
    routing against it produced six net shorts. The parser agreed with what was
    intended, which is what made it dangerous.
    - The MCP pcb_add_zone tool returns a UUID but creates no zone pcbnew can see,
    and rewriting the file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
2026-08-28 Wheel Module (M3): Veroboard stripboard layout, 0 DRC errors
    Third build option, in its own file. The plain-perfboard layout is untouched;
    the two are not interchangeable and both stay documented.
    The owner's stock is now continuous-strip Veroboard, which invalidates the
    point-to-point layout outright: every axial part there lies flat along a single
    row, so both its pads land on the same strip, and the Pico straddles cols 9/16
    with one pin on each side of every row it occupies.
    28 x 30 holes, 73.66 x 78.74 mm. Strips run horizontally on B.Cu, link wires on
    F.Cu. 23 cuts, 12 link wires, 571 grid holes netted to the strip they sit on.
    The layout turns on one rule: a strip is shared by every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
    [haptic-console-wheel-module-stripboard.kicad_pcb]
2026-08-28 Wheel Module (M3): stripboard layout as data, engine extracted to a shared repo
    The board is now generated, not hand-built. `scripts/layout.py` holds the layout
    as pure data -- grid, placement, cuts, links, invariants -- and imports no
    pcbnew, so it can be read and diffed under any Python. The engine that turns it
    into copper lives in `~/KiCad/kicad-stripboard`, a standalone repo alongside
    `jumper-wires-kicad`, so the other board projects can use it.
    The split fell out cleanly because only the data was ever project-specific. The
    five scripts that built this board were otherwise generic, including all the
    pcbnew workarounds.
    Keeping the engine shared rather than copying it also avoids a tra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
    [layout.py]
2026-08-28 Wheel Module (M3): model the link wires as jumper wires on the solder side
    The nine physical link wires are now drawn as colour-coded 3D jumper wires, so
    the render shows the board as it will actually be built rather than as bare
    copper. Colours follow the control unit's convention, so a net is the same
    colour on every board in the console: red power, blue GND (the kit has no
    black), yellow for the I2C/IRQ bus, green for /LNK.
    They run on the SOLDER side. The component side is crowded -- the Pico spans
    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
    [haptic-console-wheel-module-stripboard.kicad_pcb]
2026-09-03 Wheel Module (M3): C1 becomes a polarised 10uF 25V electrolytic
    The owner's actual part is a D4x7 aluminium electrolytic, not the ceramic disc
    the first revision specified. Bulk capacitance is what electrolytics are for,
    so this is the right part rather than a substitution -- the ceramic was only
    ever chosen to dodge a tooling bug (see below).
    Schematic: C1 is now Device:C_Polarized with a Voltage field of 25V. Pin 1 was
    already +5V and pin 2 GND on all three boards, which is exactly the polarised
    convention, so nothing needed rotating or re-netting. ERC 0 violations; the
    netlist is unchanged apart from C1's footprint -- 13 components, 39 nets, zero
    net-membership differences.
    New project-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
    [haptic-console-wheel-module-perfboard.kicad_pcb, haptic-console-wheel-module-stripboard.kicad_pcb, haptic-console-wheel-module.kicad_pcb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]
2026-09-03 Wheel Module (M3): R4/R5 go from 220R to 330R
    The two GPIO series protection resistors on /ENC_A and /ENC_B change value.
    Nothing else moves: same footprint, same pads, same nets, so this is a value
    edit on all three boards plus the generated documentation.
    Schematic edited with the MCP symbol-property tool, the fabricated board and
    the perfboard with pcbnew's SetValue, and the stripboard rebuilt from the
    updated perfboard seed (strip audit clean - every segment carries one net).
    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
    [haptic-console-wheel-module-perfboard.kicad_pcb, haptic-console-wheel-module-stripboard.kicad_pcb, haptic-console-wheel-module.kicad_pcb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]
2026-09-04 Wheel Module (M3): README gets the renders, guide links and the real board
    The README described three board builds without ever showing one. Embed the
    schematic, both stripboard sides, the perfboard and both fabricated-PCB layers
    in a new "Layouts and build guides" section, with a table pointing each build at
    its guide - including the interactive stripboard HTML, which was only reachable
    by reading a path out of a Status bullet.
    Also adds a photo of the module as actually built and hand-wired, and trims the
    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
2026-09-04 docs: add optical encoder (J2) and console (J1) wiring guide
